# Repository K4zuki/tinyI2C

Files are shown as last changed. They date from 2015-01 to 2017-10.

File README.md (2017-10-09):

tinyI2C{-}
=======

This is a tiny UART-I2C converter software/hardware project using mbed conpatible microcontrollers.
The module converts UART command packets into I2C/SPI protocol or GPIO to read/write with
configurable pull-up/pull-down modes.

- the "FTDI" USB-UART cable to connect to host PC; from PC the module look only an USB-Serial port
    - up to 115200 boudrate UART to communicate
- up to 4 channel I2C ports with selectable speed
- one SPI port with 8/16 bits word, also selectable speed
- up to 2 x 8bit, General Purpose IO ports

```
TinyI2C/         <-- root
├── doc/      <-- document source
├── gui/      <-- PyQt4 based GUI source codes
├── mbed/     <-- mbed source codes
├── pcb/      <-- PCB design files for eagle
└── python/   <-- python module code with standalone test program
```

# Requirement
- Python 3
  `apt-get install python3`
- PySerial
  `pip3 install pyserial`
* mbed microcontrollers using LPC824(recommended)/LPC1768/LPC11U24/LPC11U35
  see [mbed.org](developer.mbed.org)

# Install
1. install python 3.3+ on your PC
2. install PySerial
3. (Windows only) if you use LpcXpresso 824 then install [mbed Serial port driver](http://developer.mbed.org/handbook/Windows-serial-configuration)

# Usage
1. write mbed program into your mbed
2. connect mbed to PC via Serial port
3. start gui software
4. select Serial port from dropdown list
5. you will be able to use up to 4 channels of I2C slaves and more!
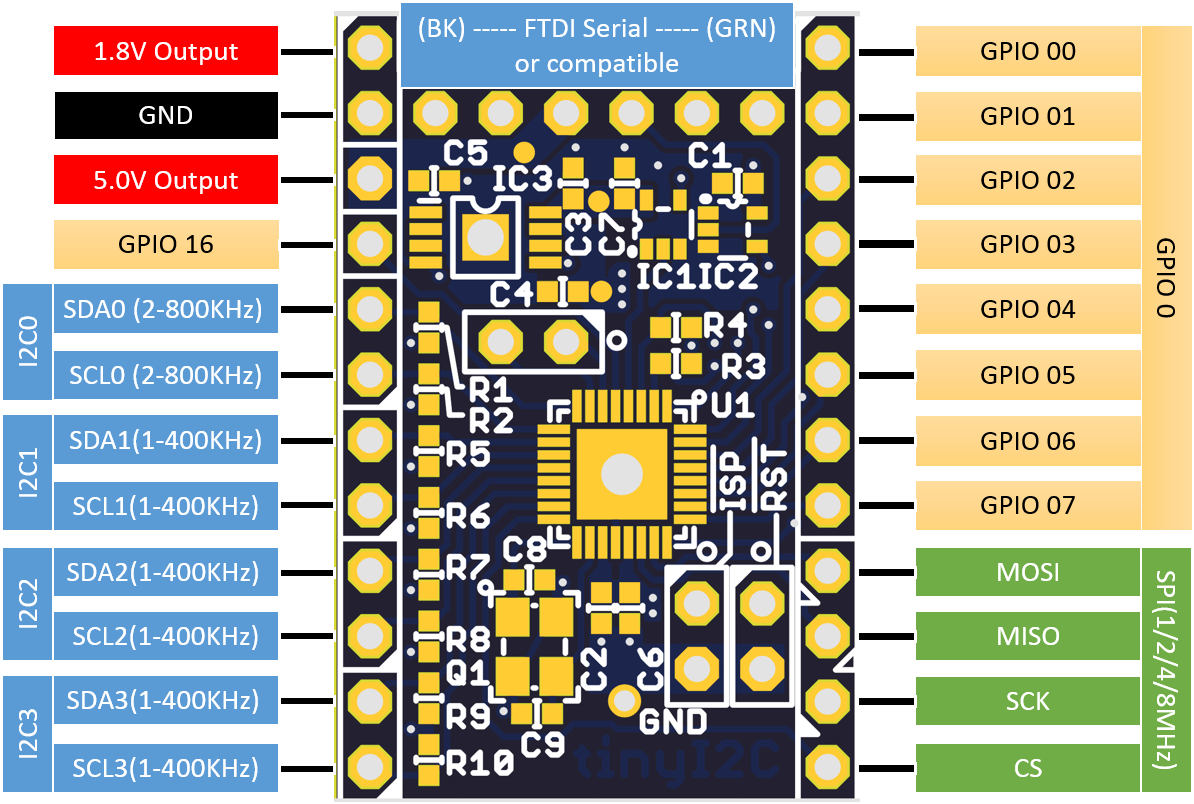
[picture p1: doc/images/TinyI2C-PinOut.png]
    * check PinOut for your usage! 

# Demo
  try `python/test.py`

## Demo GUI
GUI source codes placed in `gui/` which requires compilation
 (for now, _do it yourself_ basis).

GUI setup requires:

- PyQt5
- pyinstaller

```
$ pip3 install pyqt5 pyinstaller
```

### Compile GUI
On project root,
```
$ make gui
```

### Run GUI
On project root,
```
$ dist/TinyI2C
```

# Command set and protocol
- _this command character as well as packet structure is inspired(some copied) from
NXP Semiconductor's UART-I2C converter/controller, named **SC18IM700**._

- the command packet starts/ends with few number of characters: for starting(`head`)
character there are several choices but ending(`tail`) is always `'P'`, 0x50 in hex.
    - if only sending 'P', `tinyI2C` makes stop condition pulse (**without start condition**)
  on currently selected I2C bus and returns "ok" return packet.
- the `tinyI2C` watches its UART port \_Forever until_ it receives `tail`
  and counts received packet length by bytes (`plength`).
  then searches first character of the packet whether if matches one of registered `head` character.
    - if it does not match with any of valid `head` the device returns
  "command is not implemented" return packet.
- if valid head found it checks `plength-2` which is actual data packet length.
    - if you send an invalid packet, the device returns "bad packet" return packet.

## I2C
### `'S'` 0x53 I2C-bus START
### `'P'` 0x50 I2C-bus STOP, end of packet
- the protocol starts from `'S'`, which makes start condition on I2C bus, followed by 7bit I2C slave address and read(1)/write(0) command bit and,
  - to *Write* data into slave device: send data length to write(1~255) and actual data
  - to *Read* data from slave device: send data length to read(1~255)
- ends with sending `'P'` which makes stop condition on the bus
- return packet depends on command:
  - first, `"ACK"` or `"NAK"` depends on response from slave
  - *Read*: read data in hex sting (0xAA -> "AA") separated by ',' and ends by `ok`
  - *Write*: `ok`

- command packet: write 4 bytes to slave at 0x80(8bit)

| head  | slave address(W) | data length | binary data to write | tail  |
|:-----:|:---:|:---:|:---:|:-----:|
| S | 0x\_8 \_0 |  0x\_0 \_4  | 0x_D \_E \_A \_D \_B \_E \_A \_F | P |
| `'S'` | `'80'` | `'04'` | `'=>:=;>:?'` | `'P'` |
| 0x53  | 0x38 0x30 |  0x30 0x34  | 0x3D 0x3E 0x3A 0x3D 0x3B 0x3E 0x3A 0x3F | 0x50  |

- return packet

| result | head  | delimiter | tail |
|:---:|:-----:|:---:|:----:|
| sucess | "ACK" | , | "ok" |
|  fail  | "NAK" | , | "ok" |

- command packet: read 4 bytes from slave at 0x80(8bit)

| head | slave address(R\) | data length | tail |
|:----:|:---:|:---:|:----:|
|  S | 0x\_8 \_1 |  0x\_0 \_4  |  P |

- return packet

| result | head  | delimiter | data | tail |
|:---:|:-----:|:---:|:---:|:----:|
| sucess | "ACK" | , | actual data: "AA","BB","CC","DD", | "ok" |
|  fail  | "NAK" | , | dummy data: "C4","FE","E0","CA",  | "ok" |

- command packet: write and read 4 bytes to/from slave at 0x80(8bit)

| head | slave address(W) | data length | binary data to write | repeated start | slave address(R\) | data length | tail |
|:----:|:---:|:---:|:---:|:---:|:---:|:---:|:----:|
|  S | 0x\_8 \_0 |  0x\_0 \_4  | 0x_D \_E \_A \_D \_B \_E \_A \_F | S | 0x\_8 \_1 |  0x\_0 \_4  |  P |

- return packet

| result | head  | delimiter | data | tail |
|:---:|:-----:|:---:|:---:|:----:|
| sucess | "ACK" | , | actual data: "AA","BB","CC","DD", | "ok" |
|  fail  | "NAK" | , | dummy data: "C4","FE","E0","CA",  | "ok" |

### `'C'` 0x43 change channel
- you can select I2C channel by sending `'C'` and channel number `'0'`to`'3'` with `tail` char.

| head | channel | tail |
|:----:|:---:|:----:|
|  C | '0' |  P |
|  C | '1' |  P |
|  C | '2' |  P |
|  C | '3' |  P |

## SPI
### `'E'` 0x45 SPI transfer start

- minimum plength=8

| head | data length(W) | data length(R\) | binary data to write | tail |
|:----:|:---:|:---:|:---:|:----:|
|  E | 0x\_0 \_1 | 0x\_0 \_0 | 0x\_D \_E |  P |

- minimum plength=10(16bit)

| head | data length(W) | data length(R\) | binary data to write | tail |
|:----:|:---:|:---:|:---:|:----:|
|  E | 0x\_0 \_1 | 0x\_0 \_0 | 0x_D \_E \_A \_D |  P |

- write and read

| head | data length(W) | data length(R\) | binary data to write | tail |
|:----:|:---:|:---:|:---:|:----:|
|  E | 0x\_0 \_4 | 0x\_0 \_4 | 0x_D \_E \_A \_D \_B \_E \_A \_F |  P |

<!--
~~~
/*
"0|   1   2|   3   4|   5   6  7  8  9 10 11 12|13" //plength=14
"E| 0x\_0 \_1| 0x\_0 \_0| 0x_D \_E| P"                   //minimum plength=8
"E| 0x\_0 \_1| 0x\_0 \_0| 0x_D \_E|_A \_D| P"             //minimum plength=10(16bit)
"E| 0x\_0 \_4| 0x\_0 \_0| 0x_D \_E \_A \_D \_B \_E \_A \_F| P" //write
"E| 0x\_0 \_4| 0x\_0 \_4| 0x_D \_E \_A \_D \_B \_E \_A \_F| P" //write and read
*/
~~~
-->

## GPIO
This is a subset of [R/W commands](#internal-registers); only access GPIO's status registers.

### `'I'` 0x49 read GPIO port register
### `'O'` 0x4F write to GPIO port register

| head | GPIO | tail |
|:----:|:----:|:----:|
|  I | '0'  |  P |
|  I | '1'  |  P |

| head | GPIO | data | tail |
|:----:|:----:|:---:|:----:|
|  O | '0'  | 0x\_A \_A |  P |
|  O | '1'  | 0x\_A \_A |  P |

| register | name in python | purpose |
|:---:|:---:|:---|
| 0 | GPIO0_STAT | status of GPIO 0 |
| 1 | GPIO1_STAT | status of GPIO 1 |

## Internal registers
### `'R'` 0x52 read internal register
### `'W'` 0x57 write to internal register
- single register read

| head | register | tail |
|:----:|:---:|:----:|
|  R | '0' |  P |
|  R | '1' |  P |

- multi registers read

| head | register(1) | register(2) | ... | register(n) | tail |
|:----:|:---:|:---:|:---:|:---:|:----:|
|  R | '0' | '1' | ... | '5' |  P |
|  R | '1' | '0' | ... | '9' |  P |

- return packet's order is same as command packet's order

: multi registers write

| head | register(1) | register data (1) | register(2) | register data (2) | ... | register(n) | register data (n) | tail |
|:----:|:---:|:---:|:---:|:---:|:---:|:---:|:---:|:----:|
|  W | '0' | 0x\_A \_A | '1' | 0x\_A \_B | ... | '5' | 0x\_A \_D |  P |
|  W | '1' | 0x\_A \_A | '0' | 0x\_A \_B | ... | '9' | 0x\_A \_D |  P |

- return packet's order is same as command packet's order

| register | name in python | purpose |
|:---:|:---:|:---|
| 0 | CHIP_ID | converter's chip ID |
| 1 | GPIO0_STAT | status of GPIO 0 |
| 2 | GPIO1_STAT | status of GPIO 1 |
| 4 | GPIO1_CONF | GPIO 0 IO configuration |
| 3 | GPIO0_CONF | GPIO 1 IO configuration |
| 5 | I2C_CONF | I2C channel 1~4 speed configuration  |
| 6 | SPI_CONF | SPI speed and polarity configuration |

| register 0  | command | CHIP_ID |
|:---:|:---:|:---|
| [7\.\.\.0\] | R/W | returns chip ID character: |
| | | '0'- LPC824 |
| | | '1'- LPC1768 |
| | | '2'- LPC11U24 or LPC11U35  |

| register 1  | command | GPIO0_STAT |
|:---:|:---:|:---|
| [7\.\.\.0\] | R | behavior changes depend on corresponding bit of GPIO0_CONF register |
| | | 1: reads output setting |
| | | 0: reads input of the pin |
| | W | behavior changes depend on corresponding bit of GPIO0_CONF register |
| | | 1: writes data to the pin |
| | | 0: do nothing |

| register 2  | command | GPIO1_STAT |
|:---:|:---:|:---|
| | | **if GPIO1 is not enabled, access to this register will be ignored** |
| [7\.\.\.0\] | R | behavior changes depend on corresponding bit of GPIO1_CONF register  |
| | | 1: reads output setting |
| | | 0: reads input of the pin |
| | W | behavior changes depend on corresponding bit of GPIO1_CONF register  |
| | | 1: writes data to the pin |
| | | 0: do nothing |

| register 3  | command | GPIO0_CONF |
|:---:|:---:|:---|
| [7\.\.\.0\] | R | Reads each pin's Input/Output conditions: |
| | | 1 = the pin is set to output |
| | | 0 = the pin is set to input with internal pullup |
| | W | Sets each pin's Input/Output configurations: |
| | | 1: sets the pin to an Output. output level is set by corresponding bit of GPIO0_STAT register |
| | | 0: sets the pin to an Input with internal pull-up connected |

| register 4  | command | GPIO1_CONF |
|:---:|:---:|:---|
| | | **if GPIO1 is not enabled, access to this register will be ignored** |
| [7\.\.\.0\] | R | Reads each pin's Input/Output conditions: |
| | | 1: the pin is set to output |
| | | 0: the pin is set to input with internal pullup |
| | W | Sets each pin's Input/Output configurations: |
| | | 1: sets the pin to an Output. output level is set by corresponding bit of GPIO1_STAT register |
| | | 0: sets the pin to an Input with internal pull-up connected |

| register 5  | command | I2C_CONF |
|:---:|:---:|:---|
| [7\.\.\.6\] | R/W | Read/Write clock configuration of I2C1 |
| | | 11: I2C1 is set to operate in 800kHz clock |
| | | 10: I2C1 is set to operate in 600kHz clock |
| | | 01: I2C1 is set to operate in 400kHz clock |
| | | 00: I2C1 is set to operate in 200kHz clock |
| [5\.\.\.4\] | | Read/Write clock configuration of I2C2; **if I2C2 is not enabled, access to this bitfield will be ignored** |
| | | 11: I2C2 is set to operate in 400kHz clock |
| | | 10: I2C2 is set to operate in 300kHz clock |
| | | 01: I2C2 is set to operate in 200kHz clock |
| | | 00: I2C2 is set to operate in 100kHz clock |
| [3\.\.\.2\] | | Read/Write clock configuration of I2C3; **if I2C3 is not enabled, access to this bitfield will be ignored** |
| | | 11: I2C3 is set to operate in 400kHz clock |
| | | 10: I2C3 is set to operate in 300kHz clock |
| | | 01: I2C3 is set to operate in 200kHz clock |
| | | 00: I2C3 is set to operate in 100kHz clock |
| [1\.\.\.0\] | | Read/Write clock configuration of I2C4; **if I2C4 is not enabled, access to this bitfield will be ignored** |
| | | 11: I2C4 is set to operate in 400kHz clock |
| | | 10: I2C4 is set to operate in 300kHz clock |
| | | 01: I2C4 is set to operate in 200kHz clock |
| | | 00: I2C4 is set to operate in 100kHz clock |

| register 6  | command | SPI_CONF |
|:---:|:---:|:---|
| [7\] | R/W | Not used |
| [6\.\.\.4\] | | Read/Write clock configuration of SPI |
| | | 111: SPI is set to operate in 8MHz clock  |
| | | 110: SPI is set to operate in 7MHz clock  |
| | | ... |
| | | 001: SPI is set to operate in 2MHz clock  |
| | | 000: SPI is set to operate in 1MHz clock  |
| [3\] | | Reads/Wreite polarity of CE print |
| | | 1: CE is set to HIGH-active |
| | | 0: CE is set to LOW-active |
| [2\] | | Read/Write word size setting of SPI |
| | | 1: 16 bit word |
| | | 0: 8 bit word |
| [1\.\.\.0\] | | Read/Write SPI mode |
| | | 11: SPI is set to operate in clock mode 3 |
| | | 10: SPI is set to operate in clock mode 2 |
| | | 01: SPI is set to operate in clock mode 1 |
| | | 00: SPI is set to operate in clock mode 0 |

# Contribution by
Kazuki Yamamoto ( <k.yamamoto.08136891@gmail.com> )

# License
- [CC-BY-SA](http://creativecommons.org/licenses/by-sa/4.0/legalcode)
- [CC-BY-SA 日本語](http://creativecommons.org/licenses/by-sa/2.1/jp/legalcode)

# Author

[K4zuki](https://github.com/K4zuki)

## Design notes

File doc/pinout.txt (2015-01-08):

pin IO      func
1   P0_13   UART_RTS
2   P0_12   !ISP        _GPIO17
3   P0_5    !RESET
4   P0_4    UART_TX
5   P0_28   _GPIO16
6   P0_3    SWCLK
7   P0_2    SWDIO
8   P0_11   I2C0_SDA
9   P0_10   I2C0_SCL
10  P0_16   I2C1_SDA    _GPIO15
11  P0_27   I2C1_SCL    _GPIO14
12  P0_26   I2C2_SDA    _GPIO13
13  P0_25   I2C2_SCL    _GPIO12
14  P0_24   I2C3_SDA    _GPIO11
15  P0_15   I2C3_SCL    _GPIO10
16  P0_1    UART_CTS
17  P0_9    CS
18  P0_8    SCLK
19  VDD     VDD
20  VREFN   GND
21  VREFP   VDD
22  P0_7    MISO
23  P0_6    MOSI
24  P0_0    UART_RX
25  P0_14   _GPIO07
26  P0_23   _GPIO06
27  P0_22   _GPIO05
28  P0_21   _GPIO04
29  P0_20   _GPIO03
30  P0_19   _GPIO02
31  P0_18   _GPIO01
32  P0_17   _GPIO00
33  VSS     GND

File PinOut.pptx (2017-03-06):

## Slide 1

1.8V Output

(BK) ----- FTDI Serial ----- (GRN)
or compatible

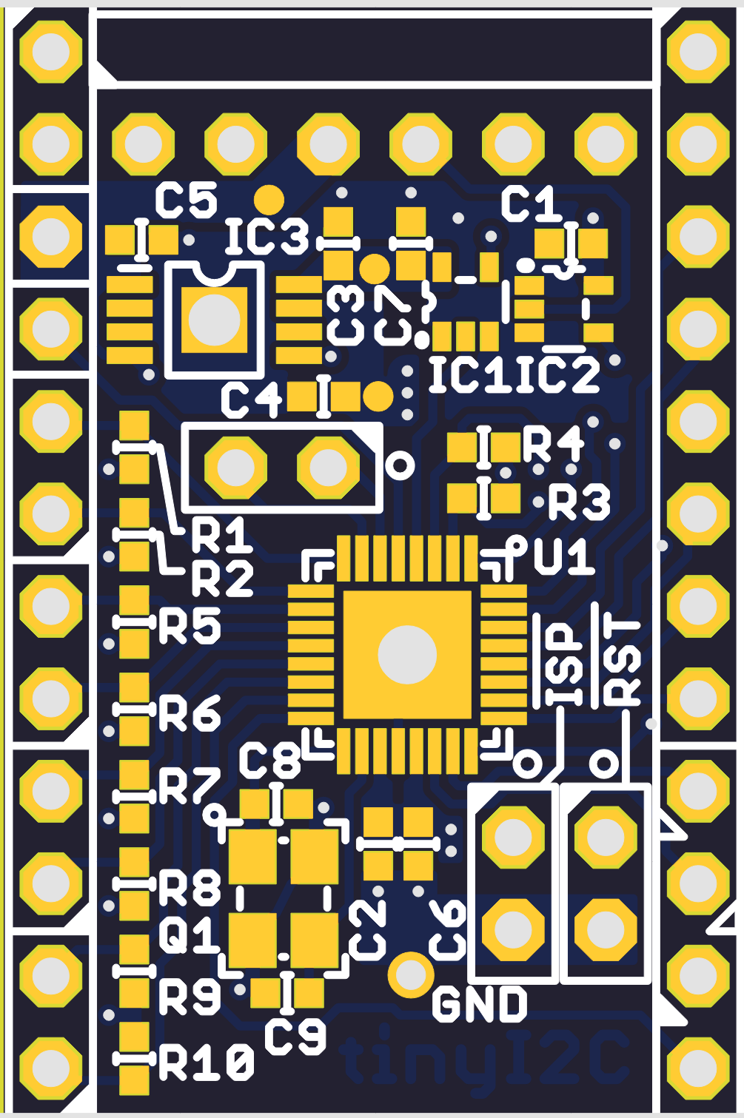
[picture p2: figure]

GPIO 00

GND

GPIO 01

5.0V Output

GPIO 16

GPIO 02

GPIO 03

SDA0 (2-800KHz)

GPIO 0

GPIO 04

I2C0

SCL0 (2-800KHz)

GPIO 05

I2C1

SDA1(1-400KHz)

SCL1(1-400KHz)

GPIO 06

GPIO 07

I2C2

SDA2(1-400KHz)

MOSI

SDA3(1-400KHz)

SCL2(1-400KHz)

MISO

SCK

SPI(1/2/4/8MHz)

I2C3

SCL3(1-400KHz)

CS

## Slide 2

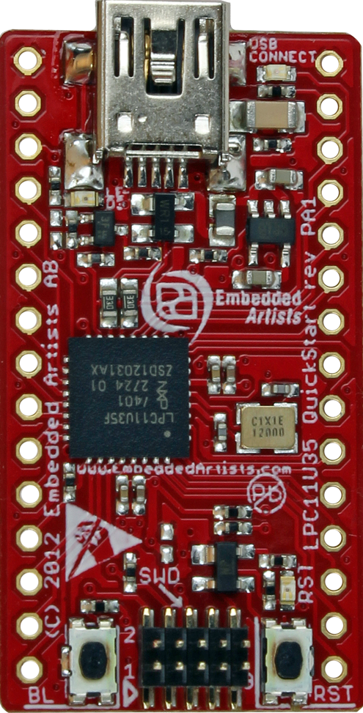
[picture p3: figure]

GND

VBUS 5.0V

GND

3.3V Output

CS

SPI(1/2/4/8MHz)

MISO

MOSI

SDA0 (2-800KHz)

SCK

SCL0 (2-800KHz)

I2C0

GPIO 00

GPIO 01

GPIO 16

GPIO 02

GPIO 15

GPIO 0

GPIO 03

GPIO 04

GPIO 14

GPIO 05

GPIO 06

GPIO 13

GPIO 07

GPIO 12

GPIO 11

GPIO 17

GPIO 10

GPIO 1

GPIO 1

GPIO 1

Image from http://www.embeddedartists.com/sites/default/files/styles/ea_photos_list/public/image/product/qsb_lpc11u35.png

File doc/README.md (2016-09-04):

+----------------+-----------+------------+------------+----------+----------+----------+------------+-------------------+-------------------+
|     Macro      |   Board   |  Function\ |            |          |          |          |            |                   |                   |
+================+===========+============+============+==========+==========+==========+============+===================+===================+
|                |           | **always**\| **always**\|          |          |          | **always**\|    **always**\    |                   |
|                |           |  **UART**  |  **I2C0**  | **I2C1** | **I2C2** | **I2C3** |  **SPI**   | **GPIO0[7\.\.0]** | **GPIO1[7\.\.0]** |
+----------------+-----------+------------+------------+----------+----------+----------+------------+-------------------+-------------------+
| **#QUAD_I2C**  | LPC824MAX |   USBTX    |  I2C_SDA   |   P0_6   |  P0_23   |  P0_21   |   P0_26    |   P0_27           |                   |
+----------------+-----------+------------+------------+----------+----------+----------+------------+-------------------+-------------------+
|                |           |   USBRX    |  I2C_SCL   |  P0_14   |  P0_22   |  P0_20   |   P0_25    |   P0_13           |                   |
+----------------+-----------+------------+------------+----------+----------+----------+------------+-------------------+-------------------+
|                |           |            |            |          |          |          |   P0_24    |   P0_17           |                   |
+----------------+-----------+------------+------------+----------+----------+----------+------------+-------------------+-------------------+
|                |           |            |            |          |          |          |   P0_15    |   P0_16           |                   |
+----------------+-----------+------------+------------+----------+----------+----------+------------+-------------------+-------------------+
|                |           |            |            |          |          |          |            |   P0_28           |                   |
+----------------+-----------+------------+------------+----------+----------+----------+------------+-------------------+-------------------+
|                |           |            |            |          |          |          |            |   P0_18           |                   |
+----------------+-----------+------------+------------+----------+----------+----------+------------+-------------------+-------------------+
|                |           |            |            |          |          |          |            |   P0_12           |                   |
+----------------+-----------+------------+------------+----------+----------+----------+------------+-------------------+-------------------+
|                |           |            |            |          |          |          |            |   P0_19           |                   |
+----------------+-----------+------------+------------+----------+----------+----------+------------+-------------------+-------------------+
| **#QUAD_I2C**\ |  TINYI2C  |    P0_4    |  I2C_SDA   |  P0_16   |  P0_26   |  P0_24   |    P0_6    |   P0_14           |                   |
| **+ #TINYI2C** |           |            |            |          |          |          |            |                   |                   |
+----------------+-----------+------------+------------+----------+----------+----------+------------+-------------------+-------------------+
| **+ #TINYI2C** |  SSCI824  |    P0_0    |  I2C_SCL   |  P0_27   |  P0_25   |  P0_15   |    P0_7    |   P0_23           |                   |
+----------------+-----------+------------+------------+----------+----------+----------+------------+-------------------+-------------------+
|                |           |            |            |          |          |          |   P0_13    |   P0_22           |                   |
+----------------+-----------+------------+------------+----------+----------+----------+------------+-------------------+-------------------+
|                |           |            |            |          |          |          |    P0_1    |   P0_21           |                   |
+----------------+-----------+------------+------------+----------+----------+----------+------------+-------------------+-------------------+
|                |           |            |            |          |          |          |            |   P0_20           |                   |
+----------------+-----------+------------+------------+----------+----------+----------+------------+-------------------+-------------------+
|                |           |            |            |          |          |          |            |   P0_19           |                   |
+----------------+-----------+------------+------------+----------+----------+----------+------------+-------------------+-------------------+
|                |           |            |            |          |          |          |            |   P0_18           |                   |
+----------------+-----------+------------+------------+----------+----------+----------+------------+-------------------+-------------------+
|                |           |            |            |          |          |          |            |   P0_17           |                   |
+----------------+-----------+------------+------------+----------+----------+----------+------------+-------------------+-------------------+
|  **#TINYI2C**  |  TINYI2C  |    P0_4    |  I2C_SDA   |          |          |          |    P0_6    |   P0_14           |   P0_12           |
+----------------+-----------+------------+------------+----------+----------+----------+------------+-------------------+-------------------+
|                |  SSCI824  |    P0_0    |  I2C_SCL   |          |          |          |    P0_7    |   P0_23           |   P0_28           |
+----------------+-----------+------------+------------+----------+----------+----------+------------+-------------------+-------------------+
|                |           |            |            |          |          |          |   P0_13    |   P0_22           |   P0_16           |
+----------------+-----------+------------+------------+----------+----------+----------+------------+-------------------+-------------------+
|                |           |            |            |          |          |          |    P0_1    |   P0_21           |   P0_27           |
+----------------+-----------+------------+------------+----------+----------+----------+------------+-------------------+-------------------+
|                |           |            |            |          |          |          |            |   P0_20           |   P0_26           |
+----------------+-----------+------------+------------+----------+----------+----------+------------+-------------------+-------------------+
|                |           |            |            |          |          |          |            |   P0_19           |   P0_25           |
+----------------+-----------+------------+------------+----------+----------+----------+------------+-------------------+-------------------+
|                |           |            |            |          |          |          |            |   P0_18           |   P0_24           |
+----------------+-----------+------------+------------+----------+----------+----------+------------+-------------------+-------------------+
|                |           |            |            |          |          |          |            |   P0_17           |   P0_15           |
+----------------+-----------+------------+------------+----------+----------+----------+------------+-------------------+-------------------+

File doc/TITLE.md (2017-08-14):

---
title: NXPのICでNXPのICをエミュレートさせてみた本
abstract: NXP社のLPCマイクロコントローラ3種でNXPのI^2^CインタフェースIC
    "SC18IM700" をエミュレートさせてみた
circle: KY技研
author: "@_K4ZUKI_"
date: 技術書典２/2017-Apr
comiket: "技術書典２"
year: "2017"
publisher: "秋葉原キンコーズで印刷製本予定"
docrevision: "1.0"
# short-hash: (git short hash)

documentclass: book
printer: true
# papersize: b5paper
# mainfont: RictyDiminished-Regular
# sansfont: RictyDiminished-Regular
# monofont: RictyDiminished-Regular
# mainlang: Japanese
# CJKoptions: BoldFont=RictyDiminished-Bold,
#   ItalicFont=RictyDiminished-Oblique,
#   BoldItalicFont=RictyDiminished-BoldOblique
# CJKmainfont: RictyDiminished-Regular
# CJKsansfont: RictyDiminished-Regular
# CJKmonofont: RictyDiminished-Regular
# geometry: top=30truemm,bottom=30truemm,left=20truemm,right=20truemm
keywords: keyword
secPrefix: Chapter
linkcolor: black
urlcolor: black
citecolor: black
chapter: true
listings: true
codeBlockCaptions: true
listingTitle: 'List'
listingTemplate: '---**$$listingTitle$$ $$i$$$$titleDelim$$ $$t$$**---'
front: images/TinyI2C-PinOut.png
---

\\newpage
# まえがき {.unnumbered}
このドキュメントは、NXP社のLPCマイクロコントローラ3種でNXPのI^2^CインタフェースIC
**`SC18IM700`** をエミュレートしつつ拡張もするプログラム群
___TinyI2Cプロジェクト___ を解説する本です。

筆者が仕事で同じスレーブアドレスのI^2^Cデバイスを複数同時に（といっても4個程度）
PCから操作する必要があったことから、USBなどとI^2^Cバスの相互通信が可能なICを
探していました。その時に見つけたのが **`SC18IM700`** でした。いろいろあって
サンプルを入手もした[^mbed_fest] のですが、必要なバスが1ポート分しかないので
別の方法を考えることにしました。

**`SC18IM700`** のコマンド体系が使いやすかったので一部をそのまま用いつつ、
例によってmbed^TM^対応マイコンを使おうと考え、 **`LPC824`** シリーズマイコンが
I^2^Cマスタ機能を _4基_ 搭載しているということから条件が一致しました。

この本は プロジェクトの概要説明とコマンドセット/Pythonライブラリ
の解説をします。いまのところ特にオチは用意してません~~がまたも６０ページ前後の
超大作になりそうです~~ 。
<!-- mbed^TM^ LPC1768 / LPC824 / LPC11U35に移植した話、TinyI2C基板の回路図、
それぞれのピン配置図ギャラリー、GUI -->

<#include "1.0_tinyI2Cabstract.md">
<#include "2.0_Commands.md">
<#include "3.0_PythonAPI.md">
<#include "9.1_RevHistory.md">

<!--  -->
[^mbed_fest]: 2014年のmbed祭りのいずれかで懇親会のおみやげにサンプルブックを入手したとかだったような

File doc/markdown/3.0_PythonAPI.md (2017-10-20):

# Python ライブラリ
この章では`TinyI2C`をPCなどから利用するためのPython実装を紹介します。
このライブラリには以下のPythonモジュール（ライブラリ）が必要です：

- PySerial

## コンストラクタ

+-------------------------------------------------------------------------------+
| **`TinyI2c(  str port = 'com1', str baud = '115200' )`**                      |
+===============================================================================+
| - **argument**                                                                |
|     - **`port`** Serial/UART port name; "COM1", "/dev/ttyUSB0" etc.           |
|     - **`baud`** UART baudrate: 115200 or need to align with firmware         |
|      setting for other rate                                                   |
+-------------------------------------------------------------------------------+
| `port`につながっている`TinyI2C`デバイスに接続する\                            |
| ＊ボーレートを変更する場合はファームウェアにも変更が必要                      |
+-------------------------------------------------------------------------------+

\\newpage
## UART操作API
+-------------------------------------------------------------------------------+
| **`TinyI2c.raw_write( str data = "C4FEE0CA"  )`**                             |
+===============================================================================+
| - **argument**                                                                |
|     - **`data`** raw data to send, as text string                             |
| - **return**                                                                  |
|     - None                                                                    |
+-------------------------------------------------------------------------------+
| 生データをUART（COMポート）に出力する                                         |
+-------------------------------------------------------------------------------+

<!--  -->

+-------------------------------------------------------------------------------+
| **`TinyI2c.raw_read(  )`**                                                    |
+===============================================================================+
| - **return**                                                                  |
|     - _ser.readline().strip()                                                 |
+-------------------------------------------------------------------------------+
|  UARTポートから生データを受け取る                                             |
+-------------------------------------------------------------------------------+

\\newpage
## I^2^Cバス操作API

+-------------------------------------------------------------------------------+
| **`TinyI2c.start(   )`**                                                      |
+===============================================================================+
| - **return**                                                                  |
|     - None                                                                    |
+-------------------------------------------------------------------------------+
|  現在のI^2^Cポートにスタートコンディションを発行する                          |
+-------------------------------------------------------------------------------+

<!--  -->

+-------------------------------------------------------------------------------+
| **`TinyI2c.stop(   )`**                                                       |
+===============================================================================+
| - **return**                                                                  |
|     - None                                                                    |
+-------------------------------------------------------------------------------+
|  現在のI^2^Cポートにストップコンディションを発行する                          |
+-------------------------------------------------------------------------------+

<!--  -->

+-------------------------------------------------------------------------------+
| **`TinyI2c.read( int address, int length = 1 )`**                             |
+===============================================================================+
| - **argument**                                                                |
|     - **`address`** *8bit* I^2^C slave address                                |
|     - **`length `** data length to read from slave                            |
| - **return**                                                                  |
|     - str raw_read()                                                          |
+-------------------------------------------------------------------------------+
| 現在のI^2^Cポートにつながっているスレーブデバイスから`length`バイト読み出す   |
+-------------------------------------------------------------------------------+

<!--  -->

+-------------------------------------------------------------------------------+
| **`TinyI2c.write( int address, int data = 0 )`**                              |
+===============================================================================+
| - **argument**                                                                |
|     - **`address`** *8bit* I^2^C slave address                                |
|     - **` data  `** data to write                                             |
| - **return**                                                                  |
|     - str raw_read()                                                          |
+-------------------------------------------------------------------------------+
| 現在のI^2^Cポートにつながっているスレーブデバイスに`data`を書き込む           |
+-------------------------------------------------------------------------------+

<!--  -->

+-------------------------------------------------------------------------------+
| **`TinyI2c.write_and_read( int address, int wdata = 0, int rlength = 1 )`**|
+===============================================================================+
| - **argument**                                                                |
|     - **`address`** *8bit* I^2^C slave address                                |
|     - **` wdata `** data to write                                             |
|     - **`rlength`** data length to read from slave                            |
| - **return**                                                                  |
|     - str raw_read()                                                          |
+-------------------------------------------------------------------------------+
| 現在のI^2^Cポートにつながっているスレーブデバイスに`data`を書き込んだあとで   |
| `length`バイト読み出す                                                        |
+-------------------------------------------------------------------------------+

<!--  -->

+-------------------------------------------------------------------------------+
| **`TinyI2c.setChannel( int channel = 0 )`**                                   |
+===============================================================================+
| - **argument**                                                                |
|     - **`channel`** I^2^C bus channel 1~4                                     |
| - **return**                                                                  |
|     - str raw_read()                                                          |
+-------------------------------------------------------------------------------+
| I^2^Cポートを変更する。Cコマンドのラッパー関数                                |
+-------------------------------------------------------------------------------+

\\newpage
## SPIバス操作コマンドAPI

+------------------------------------------------------------------------------------------------+
| **`TinyI2c.write_and_read_SPI( int wlength = 1, int rlength = 0, int data = 0xC4FEE0CA )`**    |
+================================================================================================+
| - **argument**                                                                                 |
|     - **`wlength`** _word length_ to write                                                     |
|     - **`rlength`** _word length_ to send dummy data                                           |
|     - **` data  `** valid data to write                                                        |
| - **return**                                                                                   |
|     - str raw_read()                                                                           |
+------------------------------------------------------------------------------------------------+
| SPIバスに8または16ビットデータ列を`wlength` _ワード_ 書き込んだあと                            |
| ダミーデータを`rlength` _ワード_ 書込む                                                        |
+------------------------------------------------------------------------------------------------+

\\newpage
## 内部レジスタ操作コマンド

+-------------------------------------------------------------------------------+
| **`TinyI2c.reg_read( str registers = "012" )`**                               |
+===============================================================================+
| - **argument**                                                                |
|     - **`registers`**                                                         |
| - **return**                                                                  |
|     - str raw_read()                                                          |
+-------------------------------------------------------------------------------+
| `registers`のデータをまとめて読み出す                                         |
+-------------------------------------------------------------------------------+

<!--  -->

+-------------------------------------------------------------------------------+
| **`TinyI2c.reg_write( list pair = [ ('1', 0xFF),] )`**                        |
+===============================================================================+
| - **argument**                                                                |
|     - **`pair`** list of touple                                               |
|         - **`register`** register number                                      |
|         - **`  data  `** data to write to register                            |
| - **return**                                                                  |
|     - str raw_read()                                                          |
+-------------------------------------------------------------------------------+
| それぞれの`register`に、対応する`data`を書き込む\                             |
| `register`は'0'~'6'もしくは以下の定義済み変数が使える：                       |
|                                                                               |
| - '0'     =>   `CHIP_ID`                                                      |
| - '1'     =>   `GPIO0_STAT`                                                   |
| - '2'     =>   `GPIO1_STAT`                                                   |
| - '4'     =>   `GPIO1_CONF`                                                   |
| - '3'     =>   `GPIO0_CONF`                                                   |
| - '5'     =>   `I2C_CONF`                                                     |
| - '6'     =>   `SPI_CONF`                                                     |
+-------------------------------------------------------------------------------+

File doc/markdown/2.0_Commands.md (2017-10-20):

# コマンドセットとプロトコル仕様

+-------------------------------------------------------------------------------+
| これらのコマンド文字とパケットの構造はNXP社のインタフェースIC **`SC18IM700`** |
| の仕様<sub>~~をパクっt~~</sub>に**_強く_**インスパイアされています。          |
+-------------------------------------------------------------------------------+

## 基本的なプロトコル仕様

- コマンドパケットの開始/終了には予約されている文字を1文字ずつ使います。パケットの
先頭文字(**`head`**)には何種類かありますが終端(**`tail`**)は常にアスキーの **`P`** または16進の
**`0x50`** を用います。
    - 先頭文字なしで **`P`** を送ると、現在選択されている I^2^Cバスで
    （スタートコンディション動作を起こさずに）ストップコンディション動作を行い、
    **"ok"** パケットが返却されます。
- **`head/tail`** 以外のデータはすべて1バイトを2バイトに分割して送信します。
  分割されたそれぞれの4ビットはLSBに割当てます。
  各MSBは0x03~0x0Fの任意の4ビットをマスクとして加えます。
    - 例：マスクを0x30として0x**A5** → 0x3**A** 0x3**5**
    - _0x30をマスクにするとアスキー文字列として送ることができます。_
```table
---
caption: アスキー文字一覧（抜粋）
table-width: 0.6
alignment: CCCDCCC
header: True
# inline markdown
Markdown: True
include: data/asciitable.csv
---
```

- **`tinyI2C`** モジュールはパケットを受けとるUARTポートに終端文字が送られてくるのを
(永久に)監視し続け、送られると最初にパケット文字列の長さ(`plength`)を測ります。
次に先頭文字がいずれかのコマンド文字と一致するか確認します。
    - 先頭文字が無効な場合は **"command is not implemented"** パケットが返却されます。
    - 先頭文字が有効な場合は有効文字列長(`plength - 2`：パケット長から先頭と終端
      の2文字を引いた長さ)を確認します。
        - 残念ながら文字列がそのコマンドの最低文字列長に満たない場合は **"bad packet"**
          パケットが返却されます。
    - 有効なコマンドパケットと確認できると **`TinyI2C`** モジュールはコマンドを実行し、結果を
      返却パケットとしてホストに返します。返却パケットはデータを伴う場合は各データバイトを
      16進文字列に変換し、コンマ区切りにされます。エラーでない返却パケットの終端は常に
      "ok"という文字列です。

## I^2^Cバス操作コマンド
### `'S'` 0x53 I^2^C-bus START
### `'P'` 0x50 I^2^C-bus STOP, end of packet

1. プロトコルはアスキーの **`S`** で開始され、同時に I^2^Cバスにスタートコンディションを発行します。
  その直後に7ビットの I^2^Cスレーブアドレスと`R(1)`または`W(0)`のコマンドビットが続きます。\
  このあと、
    - コマンドビットが`W(0)`（書込み）：送られるデータの長さ（1~255）と実際のデータを送る
    - コマンドビットが`R(1)`（読出し）：読みだすデータの長さ（1~255）を送る
1. パケットは **`P`** で終端します。このとき I^2^Cバスにストップコンディションを発行します。
1. 返却パケットはコマンドビットの内容に依存します。
    - 常に最初はスレーブの応答によって`ACK`または`NAK`が返ります。\
      その後、
        - コマンドビットが`W(0)`（書込み）：**`ok`** が返ります
        - コマンドビットが`R(1)`（読出し）：8ビットごとに16進数の文字列と
          終端の **`ok`** がコンマ区切りで返ります

#### 書込みのみを行う例

_8bit_ スレーブアドレス0x80に4バイト書込む コマンドパケット例

該当するI^2^Cバスの動き

返却パケット

#### 読出しのみを行う例

_8bit_ スレーブアドレス0x80から4バイト読出すコマンドパケット例

返却パケット

#### 書き込んだ後読み出す例

スレーブアドレス0x80に4バイトずつ書込み・読出しを行う コマンドパケット例

返却パケット

### `'C'` 0x43 change channel
**`C`** に続いてチャネル番号と終端を送ると I^2^Cバスを変更できます。チャネル番号は
アスキー文字の'0'~'3'です。

- _サポートされていないチャネルを選択すると強制的に**チャネル0**が選択されます。_

<!-- `Out/commandC.tmd`{.include} -->
```table
---
# caption:
alignment: CCC
table-width: 0.8
# inline markdown
markdown: True
header: True
caption: I2Cバス変更パケットの例
include: data/commandC.csv
---
```

## SPIバス操作コマンド
### `'E'` 0x45 SPI transfer start
SPIバスの操作をします。8または16ビットワードが選択できます
（詳細は[R/Wコマンド](#internal-registers)参照）。

- データ長はワード数のことです。8ビットと16ビットで最短有効パケット長が
  異なるので注意が必要です。データ長の違いは書込み/読出しともに適用されます。
  16ビットワード時に奇数バイトのデータを送ると _`bad packet`_ エラーパケットが
  返却されます。
- SPIフラッシュなど、読出しコマンドを書き込んで一気に大量に読むときは16ビット
  のほうが早く読み出せますが、コマンドが奇数バイトの場合は8ビットワードに
  する必要があります。

8ビットワードで1ワード書き込む例(minimum plength = 8)

16ビットワードで1ワード書き込む例(minimum plength = 10)

8ビットワードで2ワードずつ読み書きする例

\\newpage
## GPIO操作コマンド

```table
---
header: False
alignment: C
markdown: True
table-width: 0.8
---
これらは内部レジスタ操作コマンド（[R/Wコマンド](#internal-registers)）の
サブセットになっています。
```

**`I`** または **`O`** でプロトコルを開始します。指定できるGPIOポート番号は
`0`または`1`のみです。ハードウェアによってはポート1が存在しない場合があります。
_サポートされていないIOポートを選択すると強制的に`0xAA`を返却します。_

**`I`** コマンドでGPIOポートの状態を読むとき、または **`W`** でGPIOの状態を
変えるとき、該当するGPIOポートの設定レジスタの内容によって動作が変わります。

### `'I'` 0x49 read GPIO port register
### `'O'` 0x4F write to GPIO port register

```table
---
alignment: CCCC
table-width: 0.5
---
head,GPIO,data,tail
I,'0',,P
O,'0',0x?A ?A,P
I,'1',,P
O,'1',0x?A ?A,P
```

<!--  -->
| register | name in python | purpose |
|:---:|:---:|:---|
| 0 | GPIO0_STAT | status of GPIO 0 |
| 1 | GPIO1_STAT | status of GPIO 1 |

\\newpage
## 内部レジスタ操作コマンド {#internal-registers}
### `'R'` 0x52 read internal register
### `'W'` 0x57 write to internal register

TinyI2Cモジュール内部の設定レジスタの操作をします。
返却パッケットのデータはコマンドパケットのレジスタ指定順で返却されます。

Table: 単一レジスタから読出す例

| head | register | tail |
|:----:|:---:|:----:|
|  R | '0' |  P |
|  R | '1' |  P |

Table: 複数のレジスタから一度に読み出す例

| head | register(1) | register(2) | ... | register(n) | tail |
|:----:|:---:|:---:|:---:|:---:|:----:|
|  R | '0' | '1' | ... | '5' |  P |
|  R | '1' | '0' | ... | '9' |  P |

```table
---
# table-width:
header: True
# inline markdown
markdown: True
alignment: CCCCCCCCC
caption: multi registers write
include: data/commandRandW_multi.csv
---
```

\\newpage
#### レジスタのリスト {-}
```table
---
# table-width:
header: True
# inline markdown
markdown: True
alignment: CCC
include: data/register_list.csv
---
```

\\newpage
#### レジスタ０(CHIP_ID) {-}



```table
---
width:
  - 0.2
  - 0.5
header: True
# inline markdown
markdown: True
include: data/register0.csv
---
```

\\newpage
#### レジスタ１(GPIO0_STAT) {-}



```table
---
width:
  - 0.2
  - 0.5
header: True
# inline markdown
markdown: True
include: data/register1.csv
---
```

\\newpage
#### レジスタ３(GPIO0_CONF) {-}


<!--  -->
```table
---
width:
  - 0.2
  - 0.5
header: True
# inline markdown
markdown: True
include: data/register3.csv
---
```

\\newpage
#### レジスタ２(GPIO1_STAT) {-}



```table
---
width:
  - 0.2
  - 0.5
header: True
# inline markdown
markdown: True
include: data/register2.csv
---
```

\\newpage
#### レジスタ４(GPIO1_CONF) {-}


```table
---
width:
  - 0.2
  - 0.5
header: True
# inline markdown
markdown: True
include: data/register4.csv
---
```

\\newpage
#### レジスタ５(I2C_CONF) {-}


```table
---
width:
  - 0.2
  - 0.5
header: True
# inline markdown
markdown: True
include: data/register5.csv
---
```

\\newpage
#### レジスタ６(SPI_CONF) {-}


```table
---
width:
  - 0.2
  - 0.5
header: True
# inline markdown
markdown: True
include: data/register6.csv
---
```

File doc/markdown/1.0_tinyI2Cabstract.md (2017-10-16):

# TinyI2C プロジェクトの概要

**_TinyI2C_** はmbed^TM^ 互換のマイクロコントローラで小さなUART-I^2^C変換モジュールの
ハードウェアとソフトウェアを設計するプロジェクトです。**`TinyI2C`** モジュールは
UART^[<https://ja.wikipedia.org/wiki/UART>] で送られるコマンドパケットを変換し
I^2^CやSPI通信したり、個別にプルアップ／プルダウンを指定可能なGPIOの読み書きを行います。

## プロジェクトディレクトリツリー

<!-- ```{.plantuml im_out="img" caption="Directory Tree"}
@startsalt
{
  {T
  ""/"" (プロジェクトルート)
  + ""doc/""（ドキュメントフォルダ）
  ++ ""data/""（スクリーンショットなど）
  + ""mbed/""（ファームウェアソースコード（mbed用））
  + ""gui/""（GUIビルド用pythonソースコードとQt5プロジェクトファイル）
  + ""pcb/""（tinyI2Cハードウェアの設計ファイル）
  ++ ""tinyI2C_P/""（ガーバデータ）
  + ""python/""（pythonライブラリ）
  }
}
@endsalt
```
-->

```
(プロジェクトルート)
|
|---doc（ドキュメントフォルダ）
|   '---data（スクリーンショットなど）
|---mbed（ファームウェアソースコード（mbed用））
|---gui（GUIビルド用pythonソースコードとQt5プロジェクトファイル）
|---pcb（tinyI2Cハードウェアの設計ファイル）
|   '---tinyI2C_P（ガーバデータ）
'---python（pythonライブラリ）
```

## 特徴
- FTDI^[<http://www.ftdichip.com/>] のUSBシリアル変換ケーブル^[TODO: TinyI2Cのみ]
  またはmbedコントローラでホストのPCにつなぎます。PCからはただのUSBシリアルポートに見えます。
    - 最大115200ボーのUART通信をサポート
- 最大４チャネルの I^2^Cポートを持ち、それぞれのクロックスピードを独立に変更できます。
- SPIポートをひとつ持ち、ワード長とクロックスピードを変更できます。
- 最大２つの８ビット汎用IOポート

## 動作要件
### ソフトウェア
以下のソフトウェアをインストールしたコンピュータが必要です。
条件を満たせばラズパイでも動くと思います：

- Python 3.5^[<https://www.python.org/>]
    - もともと2.7用に開発してましたが、Python3系で動くようにライブラリ・GUIとも移植しました。
      移植後は3.5のみ動作確認してます。
- PySerialライブラリ
    - PIP(Pythonのパッケージインストーラ)で入手できます
    - `$ pip3 install pyserial`{.sh}
- **_Windowsのみ_** mbedインタフェース用のドライバ[^mbed_Serial_port_driver] を
  インストールする必要があります。

<!--  -->
[^mbed_Serial_port_driver]: <http://developer.mbed.org/handbook/Windows-serial-configuration>

### ハードウェア
以下のいずれかのマイクロコントローラを搭載したマイコンボードが必要です：

- LPC824
    - <https://developer.mbed.org/platforms/LPCXpresso824-MAX/>
    - <https://developer.mbed.org/platforms/Switch-Science-mbed-LPC824/>
- LPC11U35
    - <https://developer.mbed.org/platforms/EA-LPC11U35/>
        - **秋月的互換品が1/3程度の値段で売られてます** ：<http://akizukidenshi.com/catalog/g/gK-12144/>
    - <https://developer.mbed.org/platforms/TG-LPC11U35-501/>
- LPC1768
    - <https://developer.mbed.org/platforms/mbed-LPC1768/>

## 使い方
<!-- ### コンソールから使う場合 -->
1. mbedマイコンにファームウェアを書き込む
1. pythonコンソールを起動し、ライブラリをインポートする<!-- 2. ![TODO: console image]() -->
1. **これでもう使えます！**

## デモプログラム
コンソールでpythonディレクトリに移動して **`$ python test.py`{.sh}** を試してみてください。

```
usage: test.py [-h] [--port PORT] [--baud BAUD]
```

## GUIデモ
GUIのソースコードは **`gui`** ディレクトリに用意されています。
 いまのところ、_自力でコンパイル_ してもらう形になっています。

### GUIコンパイル要件
- PyQt5
    - **_Windowsのみ_** OSに合わせてインストーラをダウンロードする形態のようです
- pyinstaller

### GUIのコンパイルと実行
プロジェクトのルートディレクトリで
```{.sh }
$ make gui
```
とすると`dist`と`build`ディレクトリが作られます。実行可能ファイルは`dist`に置かれます。
```{.sh }
$ dist/TinyI2C
```
で実行できます。筆者の環境ではWindows/Linux/OSXとも動作確認できていますが、うまくいかないときは
```{.sh }
$ python gui/main.py
```
と実行するとなにかヒントが出るかもしれません。

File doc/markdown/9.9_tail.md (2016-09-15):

\newpage
\thispagestyle{empty}
\checkoddpage\ifoddpage\cleardoublepage\else\clearpage\fi
\thispagestyle{empty}
\vspace*{100ex}

| NXPのICでNXPのICをエミュレートしてみた本 |
|:----------------------------------------:|
|                  KY技研                  |
|               @\_K4ZUKI\_                |
|       Markdown x Pandoc x \XeLaTeX       |
|       Revision 1.0 / C91 / (hash)        |
|        秋葉原キンコーズで印刷製本        |

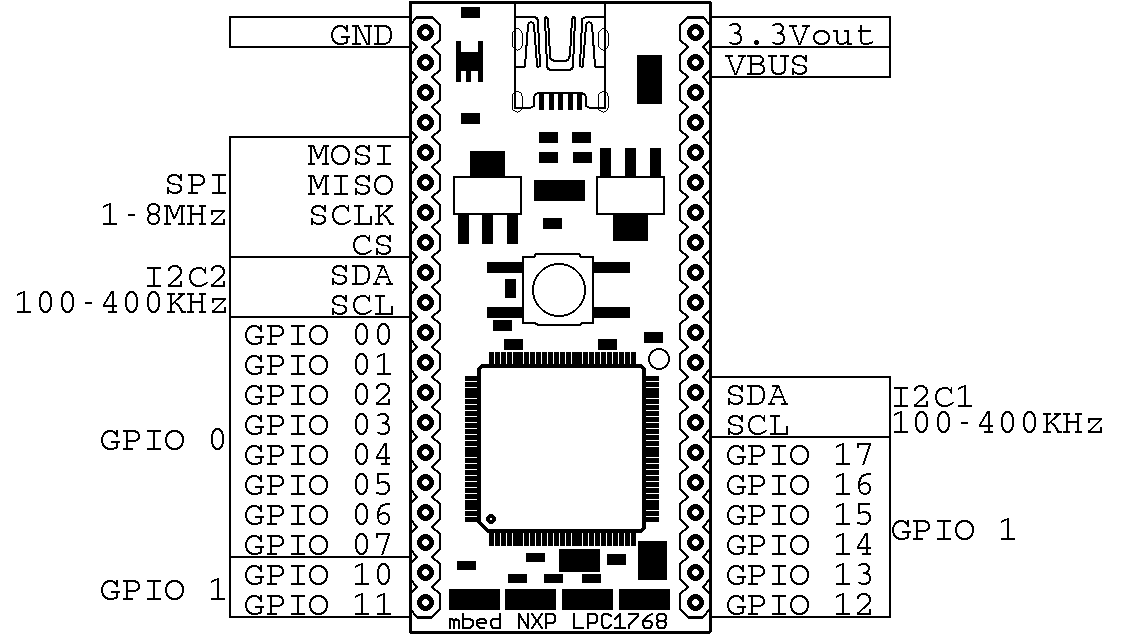
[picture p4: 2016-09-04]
doc/LPC1768_pin.png

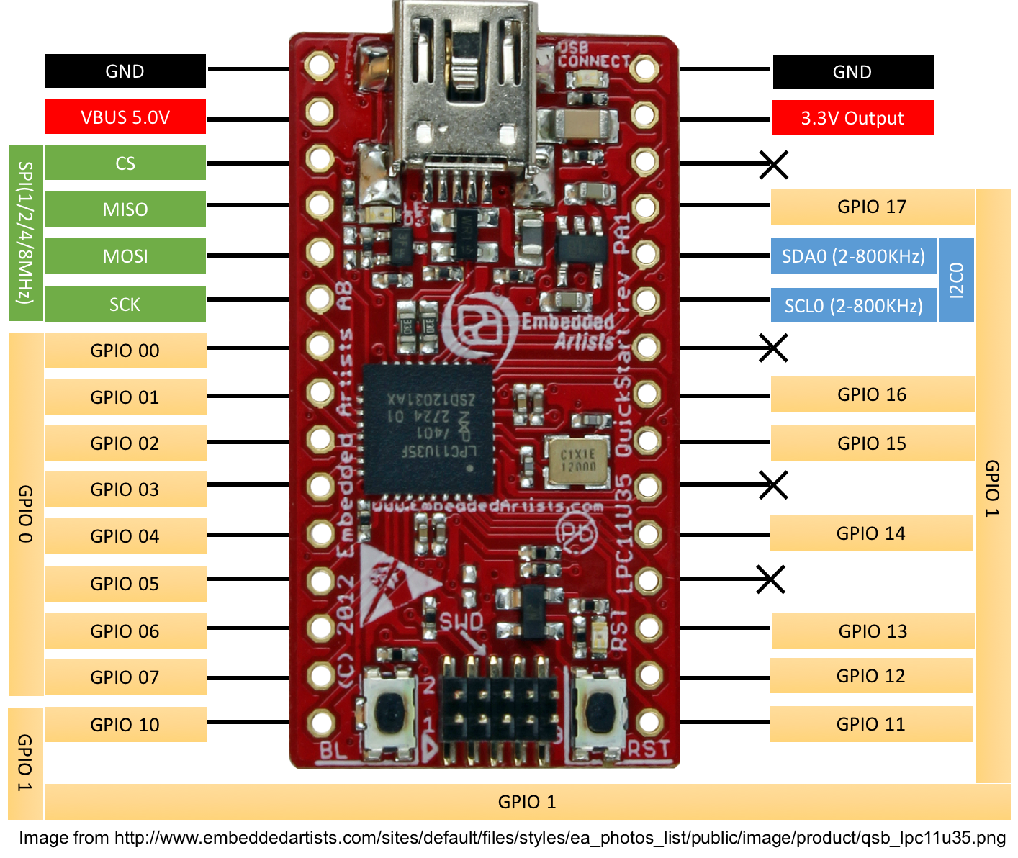
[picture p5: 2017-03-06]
doc/images/TinyI2C_11U35.png

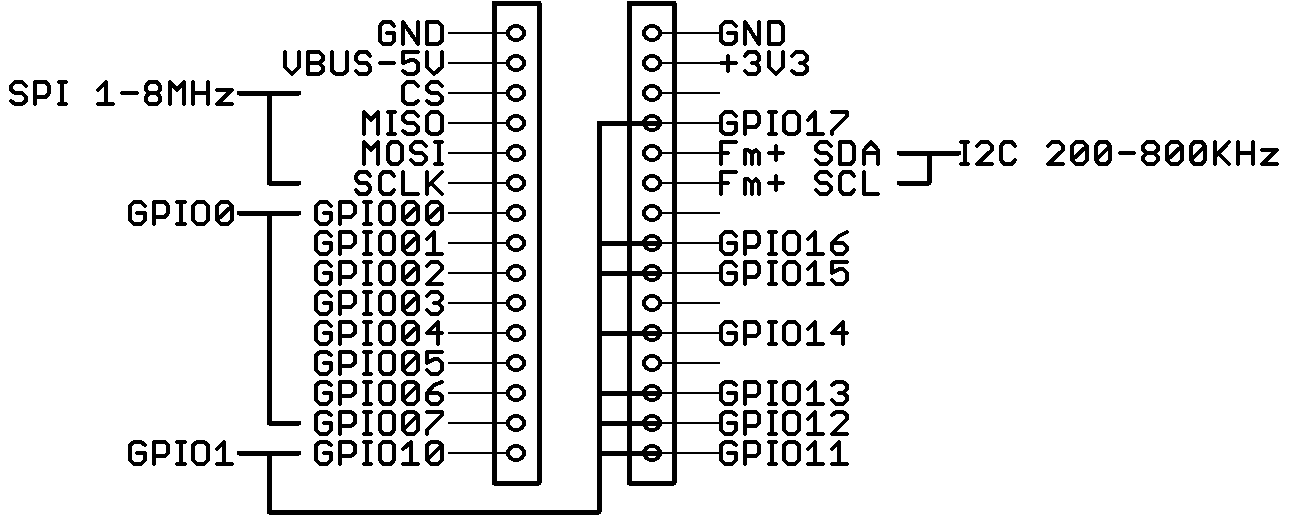
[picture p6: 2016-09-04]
doc/LPC11U35_pin.png

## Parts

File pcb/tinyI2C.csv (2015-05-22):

Qty | Value | Device | Package | Parts | Description
4 | 0.1u/1005 | C_PAD_PAD_1005 | C0402 | C1, C2, C6, C7 | SMD CAPACITOR : PAD - PAD
8 | 10k/1005 | R_US_PAD_PAD_1005 | C0402 | R3, R4, R5, R6, R7, R8, R9, R10 | R_US_PAD_PAD : SMD R PAD is NTH-NTH
3 | 10u/1005 | C_PAD_PAD_1005 | C0402 | C3, C4, C5 | SMD CAPACITOR : PAD - PAD
1 | 12MHz | XTAL-4-3225 | NX3225 | Q1 | Classic 4-pin 3.2 x 2.5mm crystal
2 | 18p/1005 | C_PAD_PAD_1005 | C0402 | C8, C9 | SMD CAPACITOR : PAD - PAD
2 | 220/1005 | R_US_PAD_PAD_1005 | C0402 | R1, R2 | R_US_PAD_PAD : SMD R PAD is NTH-NTH
2 | 74LVC1G125DCK | 74LVC1G125DCK | SC70-5 | IC1, IC2 | Single Bus Buffer Gate with 3-State Output
1 | IC_LDO_MIC5355 | IC_LDO_MIC5355 | IC_08_0.65_160MIL | IC3
1 | LPC824M201JHI33 | LPC824M201JHI33 | HVQFN33 | U1
2 | TPB1,27 | TPB1,27 | B1,27 | TP3, TP7 | Test pad
3 | TPTP07R | TPTP07R | TP07R | TP1, TP2, TP6 | Test pad
2 | TPTP10R | TPTP10R | TP10R | TP4, TP5 | Test pad
3 | TSW-102-02-S-S | TSW-102-02-S-S | TSW-102-02-S-S | X4, X5, X6 | THROUGH-HOLE .025inch SQ POST HEADER
1 | TSW-106-02-S-S-RA | TSW-106-02-S-S-RA | TSW-106-02-S-S-RA | X3 | THROUGH-HOLE .025inch SQ POST HEADER
2 | TSW-112-02-S-S | TSW-112-02-S-S | TSW-112-02-S-S | X1, X2 | THROUGH-HOLE .025inch SQ POST HEADER

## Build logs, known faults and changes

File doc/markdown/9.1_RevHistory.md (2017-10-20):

# 更新履歴 {.unnumbered}
## Revision 1.0(技術書典３) {.unnumbered}
- 最初の発行。表紙に画像を埋め込むスタイルにしてみた
- C91に出す計画もあったけどずれ込みましたとさ
- 日本語文書めんどい。
    - 英語で書き上げたREADMEを日本語に書き換える作業はつらいですw 表の内容とか。
- 次はPyPiにパッケージ登録したいですね。知り合いにやり方聞いてみます。流儀がコロコロ変わるらしいので注意しないと

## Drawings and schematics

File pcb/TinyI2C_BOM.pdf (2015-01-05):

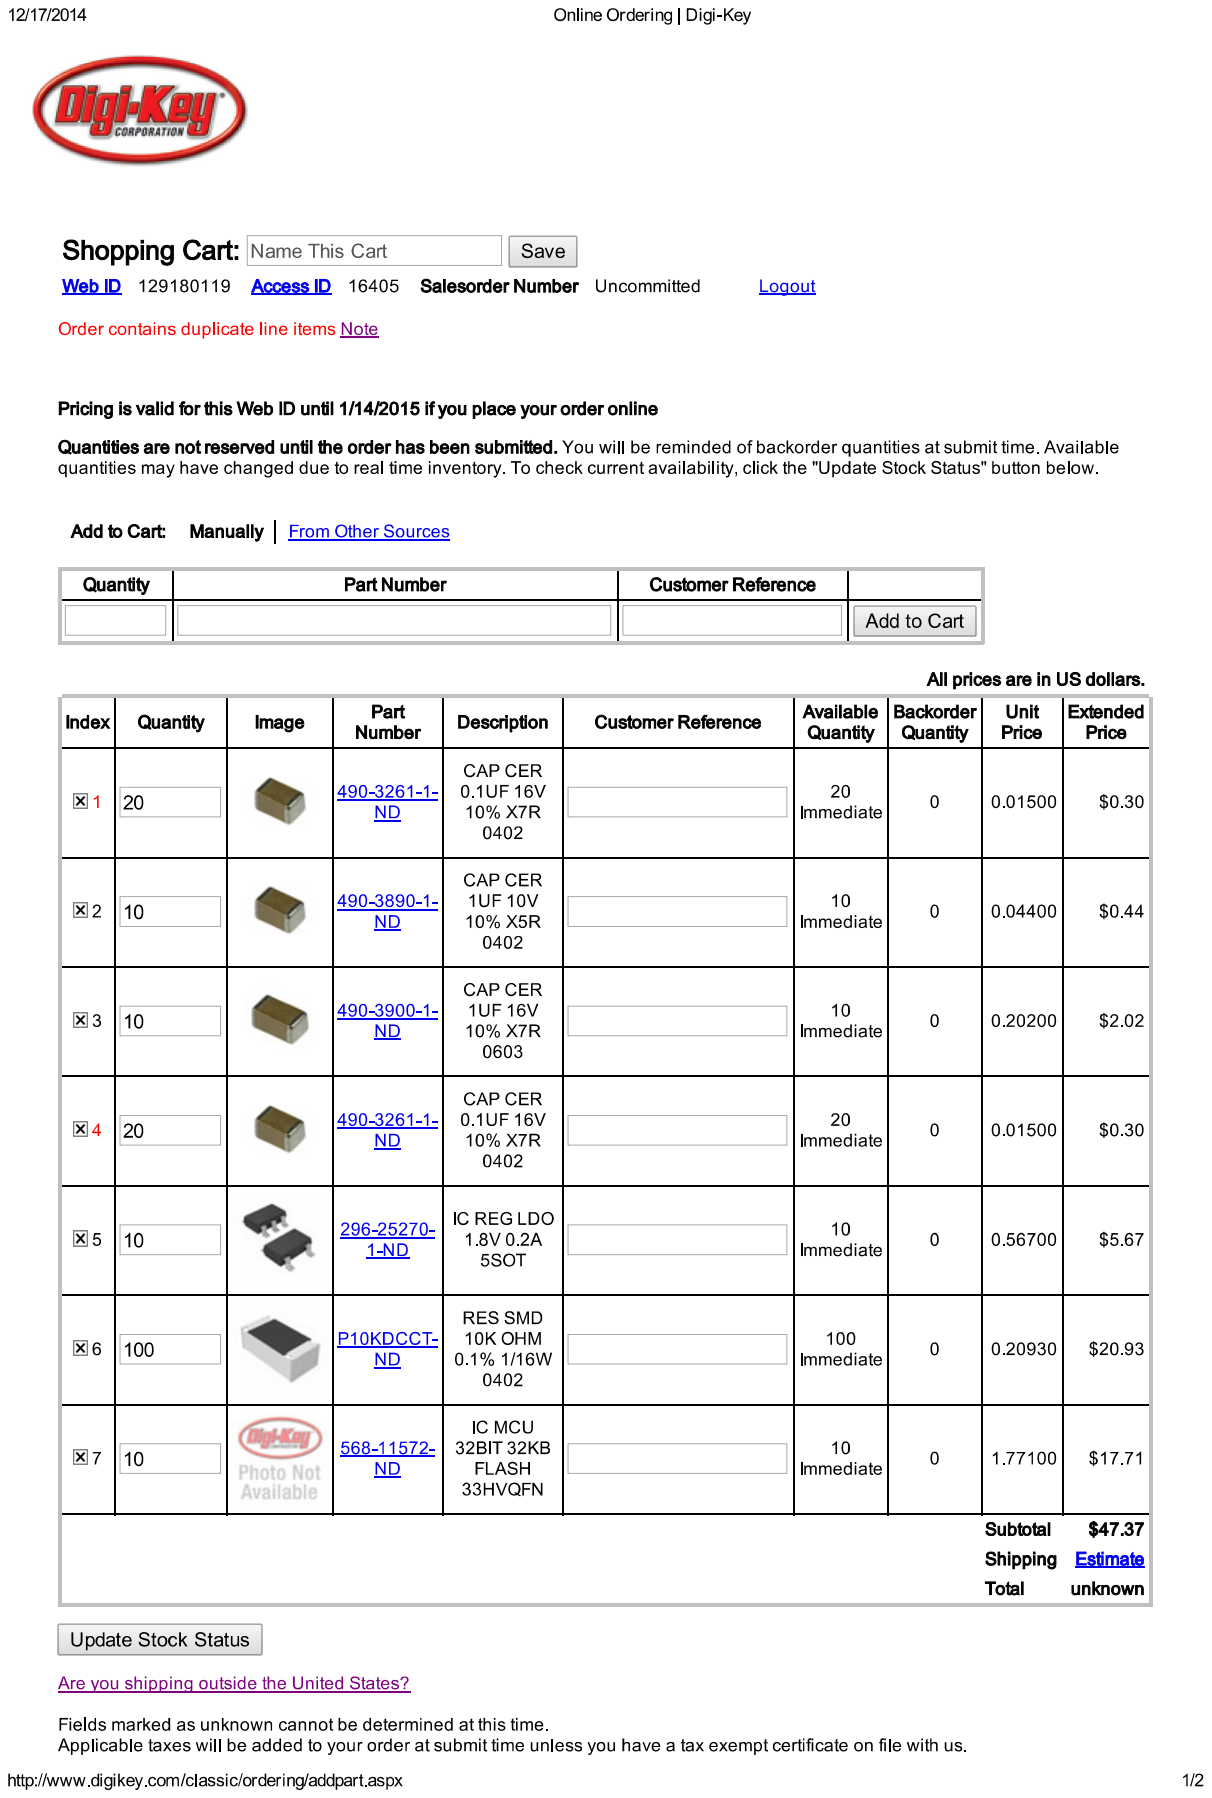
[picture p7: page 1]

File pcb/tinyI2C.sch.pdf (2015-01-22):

A

A

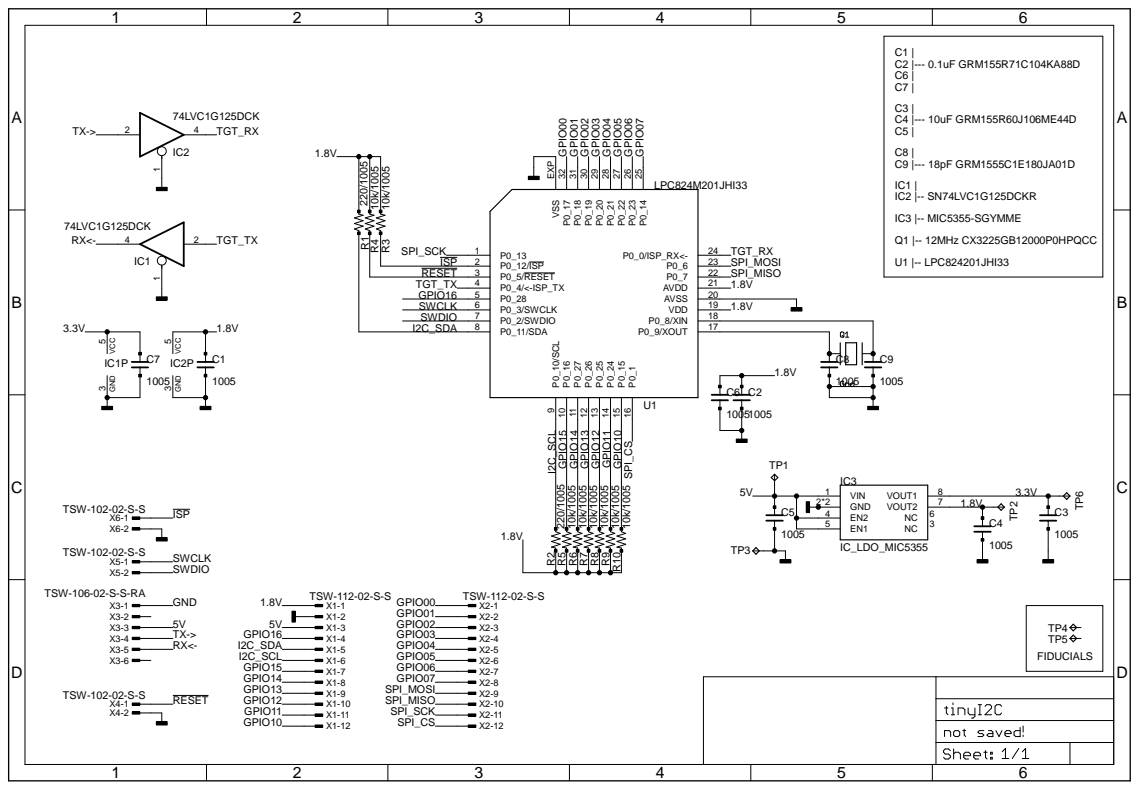
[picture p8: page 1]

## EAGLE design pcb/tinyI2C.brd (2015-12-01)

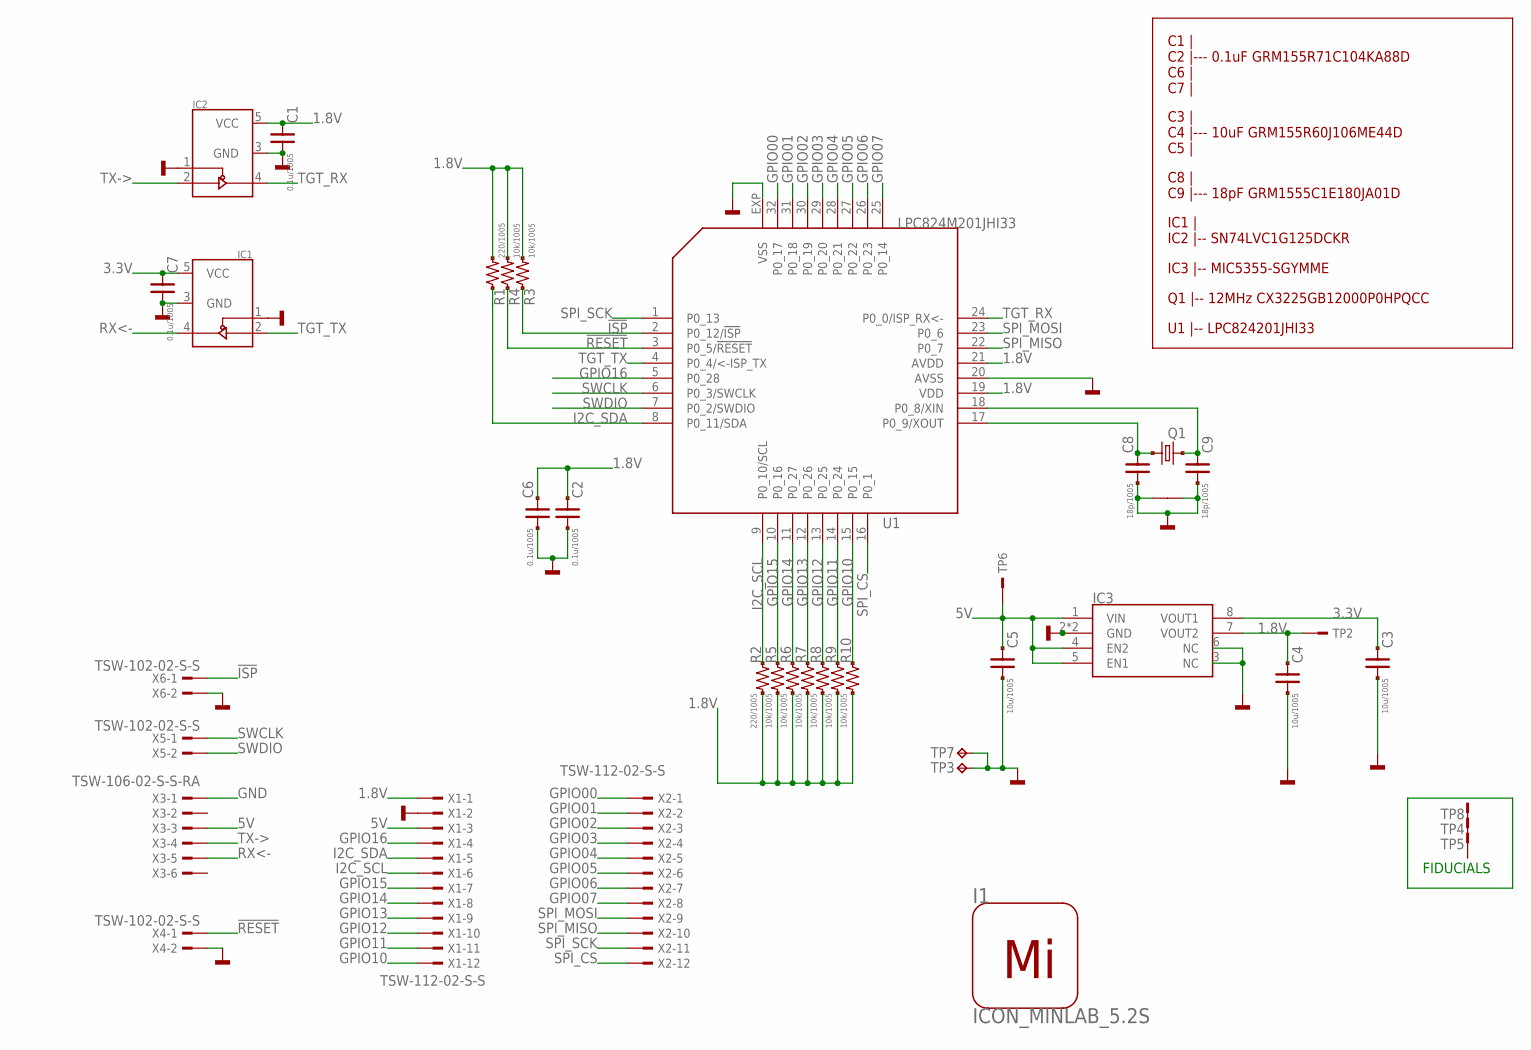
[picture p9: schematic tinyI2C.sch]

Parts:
C1, C2, C6, C7: 0.1u/1005; C0402
C3, C4, C5: 10u/1005; C0402
C8, C9: 18p/1005; C0402
I1: ICON_MINLAB_5.2S; ICON_MINLAB_5.2MM
IC1, IC2: 74LVC1G125_SC70; IC_05_0.635_40MIL
IC3: IC_LDO_MIC5355_3.3/1.8; IC_08_0.65_160MIL_EP
Q1: CRYSTAL4_12M_3225; CLOCK_3225
R1, R2: 220/1005; C0402
R3, R4, R5, R6, R7, R8, R9, R10: 10k/1005; C0402
TP2, TP6: TESTPAD; TP06RECT
TP3, TP7: TPTP14R; TP14R
TP4, TP5, TP8: TESTPAD_F; FIDUCIAL
U1: LPC824M201JHI33; HVQFN33
X1, X2: TSW-112-02-S-S
X3: TSW-106-02-S-S-RA
X4, X5, X6: TSW-102-02-S-S

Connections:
1.8V: C1.1, C2.1, C4.1, C6.1, IC2.5 (VCC), IC3.7 (VOUT2), R1.2, R2.2, R3.2, R4.2, R5.2, R6.2, R7.2, R8.2, R9.2, R10.2, TP2.TP, U1.19 (VDD), U1.21 (AVDD), X1.1
3.3V: C3.1, C7.1, IC1.5 (VCC), IC3.8 (VOUT1)
5V: C5.1, IC3.1 (VIN), IC3.4 (EN2), IC3.5 (EN1), TP6.TP, X1.3, X3.3
!ISP!: R3.1, U1.2 (P0_12/!ISP!), X6.1
!RESET!: R4.1, U1.3 (P0_5/!RESET!), X4.1
GND: C1.2, C2.2, C3.2, C4.2, C5.2, C6.2, C7.2, C8.2, C9.2, IC1.1 (!OE!), IC1.3 (GND), IC2.1 (!OE!), IC2.3 (GND), IC3.2 (GND), IC3.3 (NC), IC3.6 (NC), IC3.EXP (GND), Q1.2, Q1.4, TP3.TP, TP7.TP, U1.20 (AVSS), U1.EXP (VSS), X1.2, X3.1, X4.2, X6.2
GPIO00: U1.32 (P0_17), X2.1
GPIO01: U1.31 (P0_18), X2.2
GPIO02: U1.30 (P0_19), X2.3
GPIO03: U1.29 (P0_20), X2.4
GPIO04: U1.28 (P0_21), X2.5
GPIO05: U1.27 (P0_22), X2.6
GPIO06: U1.26 (P0_23), X2.7
GPIO07: U1.25 (P0_14), X2.8
GPIO10: R10.1, U1.15 (P0_15), X1.12
GPIO11: R9.1, U1.14 (P0_24), X1.11
GPIO12: R8.1, U1.13 (P0_25), X1.10
GPIO13: R7.1, U1.12 (P0_26), X1.9
GPIO14: R6.1, U1.11 (P0_27), X1.8
GPIO15: R5.1, U1.10 (P0_16), X1.7
GPIO16: U1.5 (P0_28), X1.4
I2C_SCL: R2.1, U1.9 (P0_10/SCL), X1.6
I2C_SDA: R1.1, U1.8 (P0_11/SDA), X1.5
unnamed: C8.1, Q1.1, U1.17 (P0_9/XOUT)
unnamed: C9.1, Q1.3 (2), U1.18 (P0_8/XIN)
RX<-: IC1.4 (Y), X3.5
SPI_CS: U1.16 (P0_1), X2.12
SPI_MISO: U1.22 (P0_7), X2.10
SPI_MOSI: U1.23 (P0_6), X2.9
SPI_SCK: U1.1 (P0_13), X2.11
SWCLK: U1.6 (P0_3/SWCLK), X5.1
SWDIO: U1.7 (P0_2/SWDIO), X5.2
TGT_RX: IC2.4 (Y), U1.24 (P0_0/ISP_RX<-)
TGT_TX: IC1.2 (A), U1.4 (P0_4/<-ISP_TX)
TX->: IC2.2 (A), X3.4

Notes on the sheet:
FIDUCIALS
C1 | C2 |--- 0.1uF GRM155R71C104KA88D C6 | C7 |
C3 | C4 |--- 10uF GRM155R60J106ME44D C5 |
IC1 | IC2 |-- SN74LVC1G125DCKR
IC3 |-- MIC5355-SGYMME
U1 |-- LPC824201JHI33
C8 | C9 |--- 18pF GRM1555C1E180JA01D
Q1 |-- 12MHz CX3225GB12000P0HPQCC

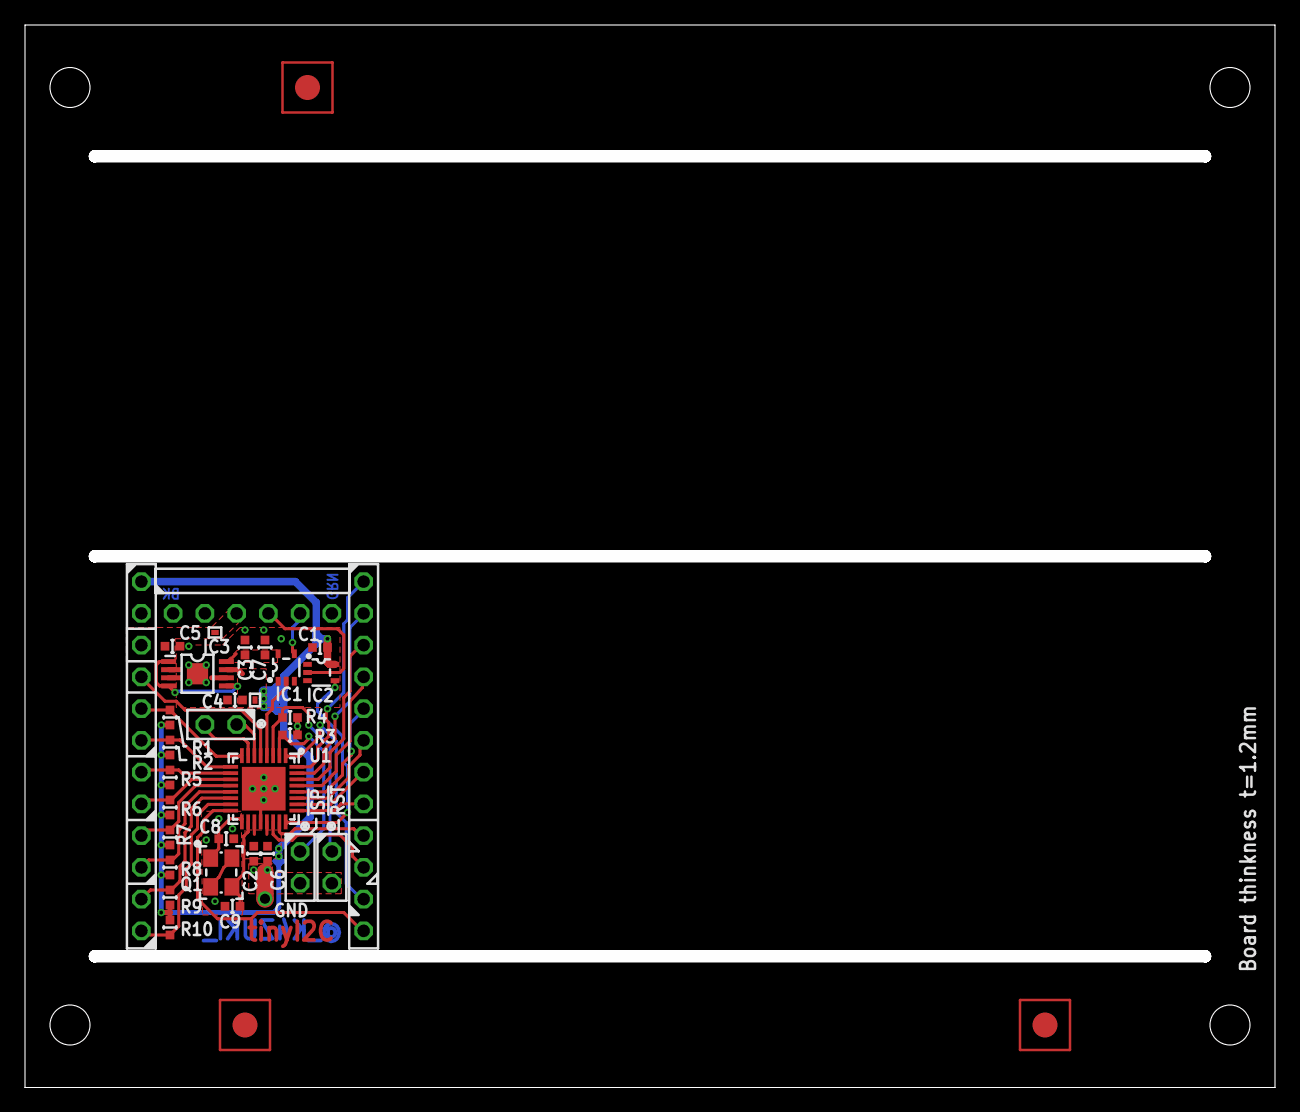
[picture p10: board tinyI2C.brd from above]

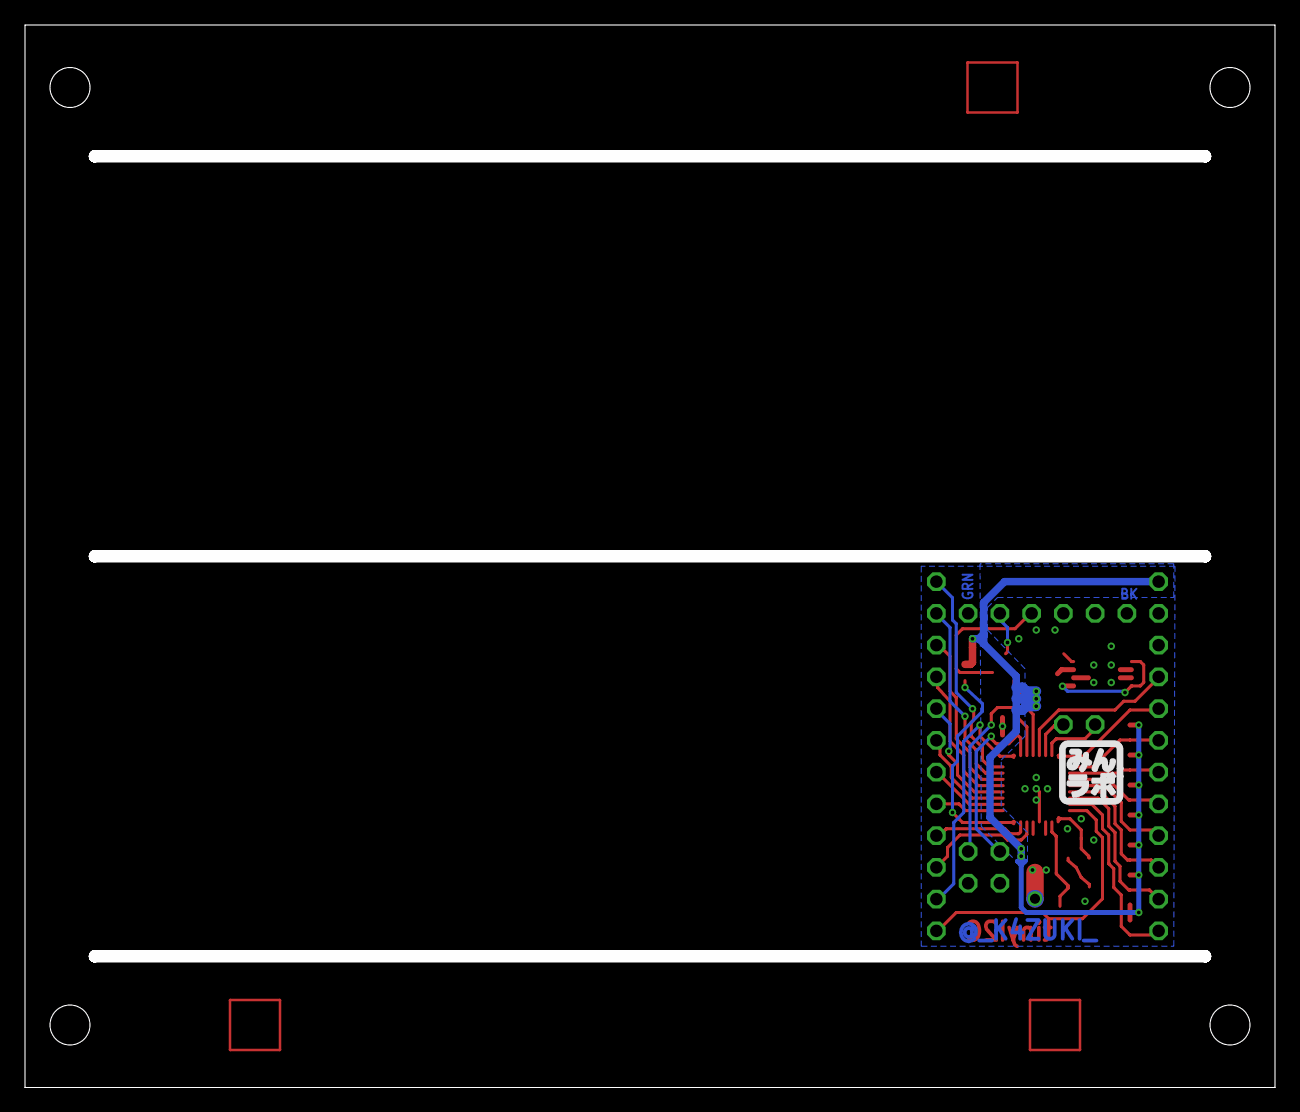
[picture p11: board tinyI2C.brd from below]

Board: 2 copper layers, 100.0 x 85.0 mm, 38 parts (2 on the bottom side), 35 nets.

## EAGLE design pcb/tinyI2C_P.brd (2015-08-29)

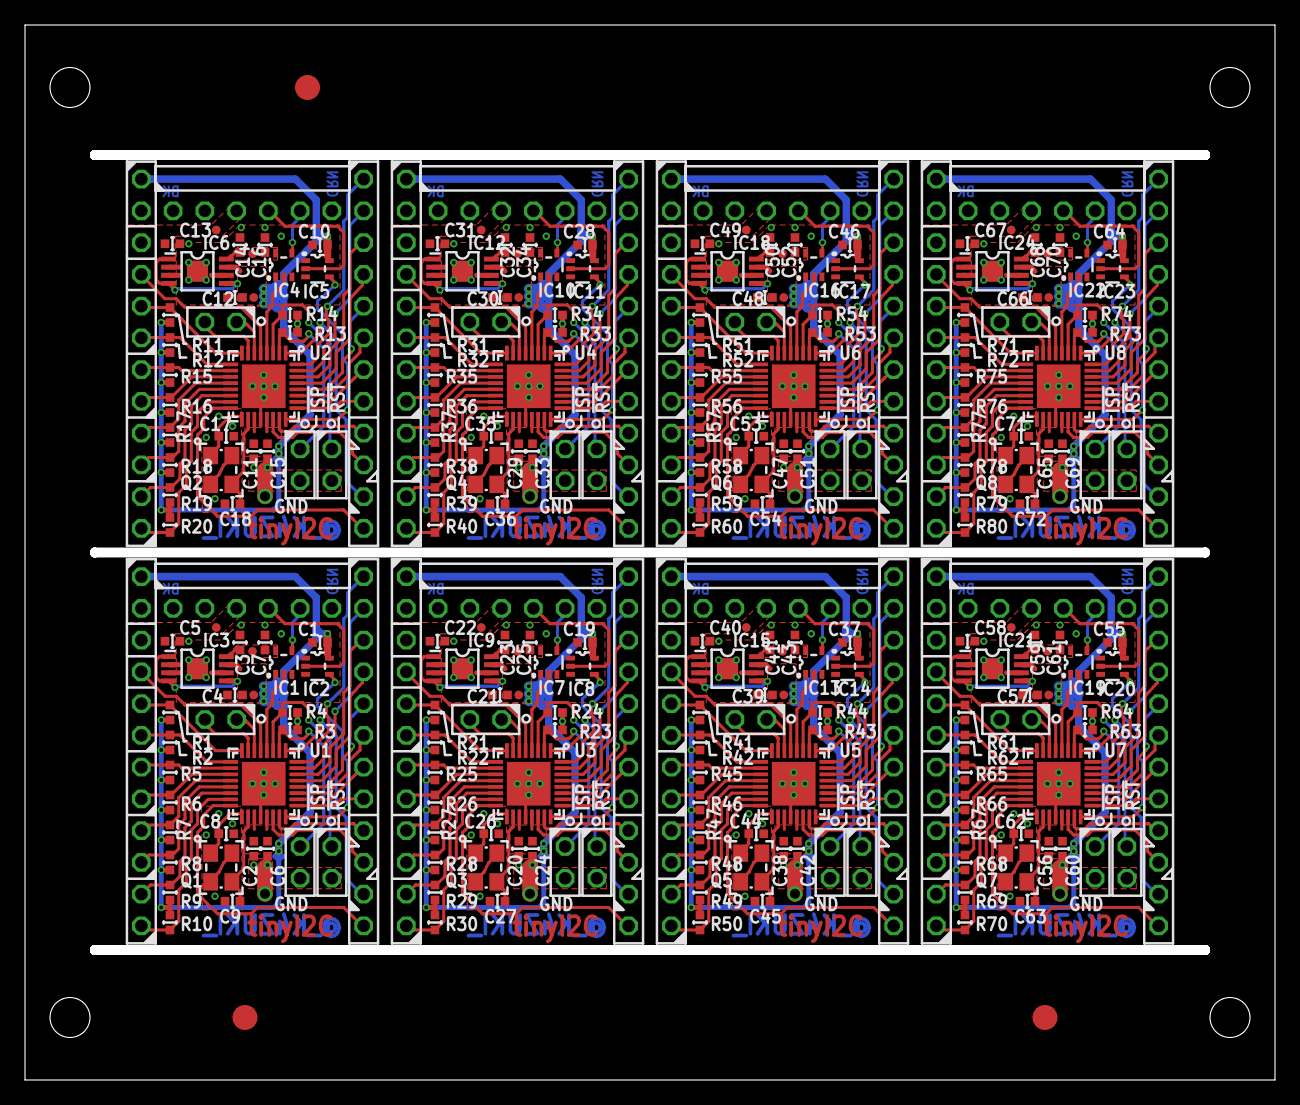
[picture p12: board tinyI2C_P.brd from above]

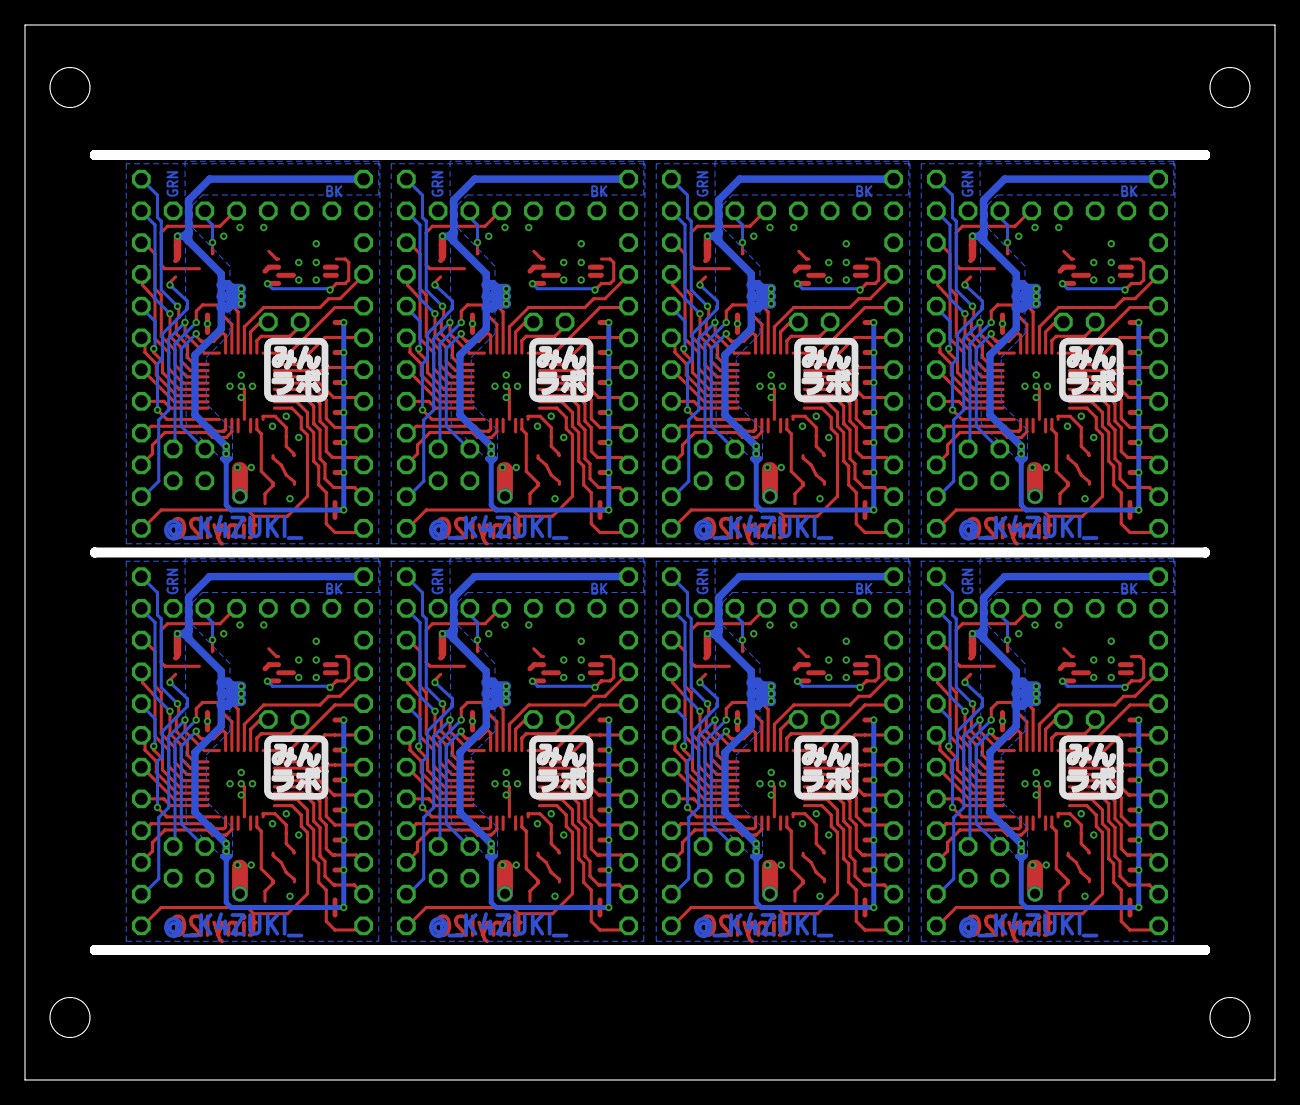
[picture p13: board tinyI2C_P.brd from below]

Board: 2 copper layers, 100.0 x 84.4 mm, 291 parts (16 on the bottom side), 280 nets.

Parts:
C1, C2, C6, C7, C10, C11, C15, C16, C19, C20, C24, C25, C28, C29, C33, C34, C37, C38, C42, C43, C46, C47, C51, C52, C55, C56, C60, C61, C64, C65, C69, C70: 0.1u/1005; C0402
C3, C4, C5, C12, C13, C14, C21, C22, C23, C30, C31, C32, C39, C40, C41, C48, C49, C50, C57, C58, C59, C66, C67, C68: 10u/1005; C0402
C8, C9, C17, C18, C26, C27, C35, C36, C44, C45, C53, C54, C62, C63, C71, C72: 18p/1005; C0402
I1, I2, I3, I4, I5, I6, I7, I8: ICON_MINLAB_5.2S; ICON_MINLAB_5.2MM
IC1, IC2, IC4, IC5, IC7, IC8, IC10, IC11, IC13, IC14, IC16, IC17, IC19, IC20, IC22, IC23: 74LVC1G125DCK; SC70-5
IC3, IC6, IC9, IC12, IC15, IC18, IC21, IC24: IC_LDO_MIC5355; IC_08_0.65_160MIL_EP
Q1, Q2, Q3, Q4, Q5, Q6, Q7, Q8: 12MHz; NX3225
R1, R2, R11, R12, R21, R22, R31, R32, R41, R42, R51, R52, R61, R62, R71, R72: 220/1005; C0402
R3, R4, R5, R6, R7, R8, R9, R10, R13, R14, R15, R16, R17, R18, R19, R20, R23, R24, R25, R26, R27, R28, R29, R30, R33, R34, R35, R36, R37, R38, R39, R40, R43, R44, R45, R46, R47, R48, R49, R50, R53, R54, R55, R56, R57, R58, R59, R60, R63, R64, R65, R66, R67, R68, R69, R70, R73, R74, R75, R76, R77, R78, R79, R80: 10k/1005; C0402
TP1, TP2, TP6, TP9, TP10, TP12, TP14, TP15, TP17, TP19, TP20, TP22, TP24, TP25, TP27, TP29, TP30, TP32, TP34, TP35, TP37, TP39, TP40, TP42: TPTP07R; TP07R
TP3, TP7, TP11, TP13, TP16, TP18, TP21, TP23, TP26, TP28, TP31, TP33, TP36, TP38, TP41, TP43: TPB1,27; B1,27
TP4, TP5, TP8: TPTP20R; TP20R
U1, U2, U3, U4, U5, U6, U7, U8: LPC824M201JHI33; HVQFN33
X1, X2, X8, X9, X14, X15, X20, X21, X26, X27, X32, X33, X38, X39, X44, X45: TSW-112-02-S-S
X3, X7, X13, X19, X25, X31, X37, X43: TSW-106-02-S-S-RA
X4, X5, X6, X10, X11, X12, X16, X17, X18, X22, X23, X24, X28, X29, X30, X34, X35, X36, X40, X41, X42, X46, X47, X48: TSW-102-02-S-S

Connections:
1.8V: C1.1, C2.1, C4.1, C6.1, IC2.5, IC3.7, R1.2, R2.2, R3.2, R4.2, R5.2, R6.2, R7.2, R8.2, R9.2, R10.2, TP2.TP, U1.19, U1.21, X1.1
1.8V1: C10.1, C11.1, C12.1, C15.1, IC5.5, IC6.7, R11.2, R12.2, R13.2, R14.2, R15.2, R16.2, R17.2, R18.2, R19.2, R20.2, TP10.TP, U2.19, U2.21, X8.1
1.8V2: C19.1, C20.1, C21.1, C24.1, IC8.5, IC9.7, R21.2, R22.2, R23.2, R24.2, R25.2, R26.2, R27.2, R28.2, R29.2, R30.2, TP15.TP, U3.19, U3.21, X14.1
1.8V3: C28.1, C29.1, C30.1, C33.1, IC11.5, IC12.7, R31.2, R32.2, R33.2, R34.2, R35.2, R36.2, R37.2, R38.2, R39.2, R40.2, TP20.TP, U4.19, U4.21, X20.1
1.8V4: C37.1, C38.1, C39.1, C42.1, IC14.5, IC15.7, R41.2, R42.2, R43.2, R44.2, R45.2, R46.2, R47.2, R48.2, R49.2, R50.2, TP25.TP, U5.19, U5.21, X26.1
1.8V5: C46.1, C47.1, C48.1, C51.1, IC17.5, IC18.7, R51.2, R52.2, R53.2, R54.2, R55.2, R56.2, R57.2, R58.2, R59.2, R60.2, TP30.TP, U6.19, U6.21, X32.1
1.8V6: C55.1, C56.1, C57.1, C60.1, IC20.5, IC21.7, R61.2, R62.2, R63.2, R64.2, R65.2, R66.2, R67.2, R68.2, R69.2, R70.2, TP35.TP, U7.19, U7.21, X38.1
1.8V7: C64.1, C65.1, C66.1, C69.1, IC23.5, IC24.7, R71.2, R72.2, R73.2, R74.2, R75.2, R76.2, R77.2, R78.2, R79.2, R80.2, TP40.TP, U8.19, U8.21, X44.1
3.3V: C3.1, C7.1, IC1.5, IC3.8, TP6.TP
3.3V1: C14.1, C16.1, IC4.5, IC6.8, TP12.TP
3.3V2: C23.1, C25.1, IC7.5, IC9.8, TP17.TP
3.3V3: C32.1, C34.1, IC10.5, IC12.8, TP22.TP
3.3V4: C41.1, C43.1, IC13.5, IC15.8, TP27.TP
3.3V5: C50.1, C52.1, IC16.5, IC18.8, TP32.TP
3.3V6: C59.1, C61.1, IC19.5, IC21.8, TP37.TP
3.3V7: C68.1, C70.1, IC22.5, IC24.8, TP42.TP
5V: C5.1, IC3.1, IC3.4, IC3.5, TP1.TP, X1.3, X3.3
5V1: C13.1, IC6.1, IC6.4, IC6.5, TP9.TP, X7.3, X8.3
5V2: C22.1, IC9.1, IC9.4, IC9.5, TP14.TP, X13.3, X14.3
5V3: C31.1, IC12.1, IC12.4, IC12.5, TP19.TP, X19.3, X20.3
5V4: C40.1, IC15.1, IC15.4, IC15.5, TP24.TP, X25.3, X26.3
5V5: C49.1, IC18.1, IC18.4, IC18.5, TP29.TP, X31.3, X32.3
5V6: C58.1, IC21.1, IC21.4, IC21.5, TP34.TP, X37.3, X38.3
5V7: C67.1, IC24.1, IC24.4, IC24.5, TP39.TP, X43.3, X44.3
!ISP!: R3.1, U1.2, X6.1
!ISP!1: R13.1, U2.2, X12.1
!ISP!2: R23.1, U3.2, X18.1
!ISP!3: R33.1, U4.2, X24.1
!ISP!4: R43.1, U5.2, X30.1
!ISP!5: R53.1, U6.2, X36.1
!ISP!6: R63.1, U7.2, X42.1
!ISP!7: R73.1, U8.2, X48.1
!RESET!: R4.1, U1.3, X4.1
!RESET!1: R14.1, U2.3, X10.1
!RESET!2: R24.1, U3.3, X16.1
!RESET!3: R34.1, U4.3, X22.1
!RESET!4: R44.1, U5.3, X28.1
!RESET!5: R54.1, U6.3, X34.1
!RESET!6: R64.1, U7.3, X40.1
!RESET!7: R74.1, U8.3, X46.1
GND: C1.2, C2.2, C3.2, C4.2, C5.2, C6.2, C7.2, C8.2, C9.2, IC1.1, IC1.3, IC2.1, IC2.3, IC3.2, IC3.3, IC3.6, IC3.EXP, Q1.2, Q1.4, TP3.TP, TP7.TP, U1.20, U1.EXP, X1.2, X3.1, X4.2, X6.2
GND1: C10.2, C11.2, C12.2, C13.2, C14.2, C15.2, C16.2, C17.2, C18.2, IC4.1, IC4.3, IC5.1, IC5.3, IC6.2, IC6.3, IC6.6, IC6.EXP, Q2.2, Q2.4, TP11.TP, TP13.TP, U2.20, U2.EXP, X7.1, X8.2, X10.2, X12.2
GND2: C19.2, C20.2, C21.2, C22.2, C23.2, C24.2, C25.2, C26.2, C27.2, IC7.1, IC7.3, IC8.1, IC8.3, IC9.2, IC9.3, IC9.6, IC9.EXP, Q3.2, Q3.4, TP16.TP, TP18.TP, U3.20, U3.EXP, X13.1, X14.2, X16.2, X18.2
GND3: C28.2, C29.2, C30.2, C31.2, C32.2, C33.2, C34.2, C35.2, C36.2, IC10.1, IC10.3, IC11.1, IC11.3, IC12.2, IC12.3, IC12.6, IC12.EXP, Q4.2, Q4.4, TP21.TP, TP23.TP, U4.20, U4.EXP, X19.1, X20.2, X22.2, X24.2
GND4: C37.2, C38.2, C39.2, C40.2, C41.2, C42.2, C43.2, C44.2, C45.2, IC13.1, IC13.3, IC14.1, IC14.3, IC15.2, IC15.3, IC15.6, IC15.EXP, Q5.2, Q5.4, TP26.TP, TP28.TP, U5.20, U5.EXP, X25.1, X26.2, X28.2, X30.2
GND5: C46.2, C47.2, C48.2, C49.2, C50.2, C51.2, C52.2, C53.2, C54.2, IC16.1, IC16.3, IC17.1, IC17.3, IC18.2, IC18.3, IC18.6, IC18.EXP, Q6.2, Q6.4, TP31.TP, TP33.TP, U6.20, U6.EXP, X31.1, X32.2, X34.2, X36.2
GND6: C55.2, C56.2, C57.2, C58.2, C59.2, C60.2, C61.2, C62.2, C63.2, IC19.1, IC19.3, IC20.1, IC20.3, IC21.2, IC21.3, IC21.6, IC21.EXP, Q7.2, Q7.4, TP36.TP, TP38.TP, U7.20, U7.EXP, X37.1, X38.2, X40.2, X42.2
GND7: C64.2, C65.2, C66.2, C67.2, C68.2, C69.2, C70.2, C71.2, C72.2, IC22.1, IC22.3, IC23.1, IC23.3, IC24.2, IC24.3, IC24.6, IC24.EXP, Q8.2, Q8.4, TP41.TP, TP43.TP, U8.20, U8.EXP, X43.1, X44.2, X46.2, X48.2
GPIO00: U1.32, X2.1
GPIO01: U1.31, X2.2
GPIO02: U1.30, X2.3
GPIO03: U1.29, X2.4
GPIO04: U1.28, X2.5
GPIO05: U1.27, X2.6
GPIO06: U1.26, X2.7
GPIO07: U1.25, X2.8
GPIO08: U2.5, X8.4
GPIO09: R15.1, U2.10, X8.7
GPIO10: R10.1, U1.15, X1.12
GPIO11: R9.1, U1.14, X1.11
GPIO12: R8.1, U1.13, X1.10
GPIO13: R7.1, U1.12, X1.9
GPIO14: R6.1, U1.11, X1.8
GPIO15: R5.1, U1.10, X1.7
GPIO16: U1.5, X1.4
GPIO17: R16.1, U2.11, X8.8
GPIO18: R17.1, U2.12, X8.9
GPIO19: R18.1, U2.13, X8.10
GPIO20: R19.1, U2.14, X8.11
GPIO21: R20.1, U2.15, X8.12
GPIO22: U2.25, X9.8
GPIO23: U2.26, X9.7
GPIO24: U2.27, X9.6
GPIO25: U2.28, X9.5
GPIO26: U2.29, X9.4
GPIO27: U2.30, X9.3
GPIO28: U2.31, X9.2
GPIO29: U2.32, X9.1
GPIO30: U3.5, X14.4
GPIO31: R25.1, U3.10, X14.7
GPIO32: R26.1, U3.11, X14.8
GPIO33: R27.1, U3.12, X14.9
GPIO34: R28.1, U3.13, X14.10
GPIO35: R29.1, U3.14, X14.11
GPIO36: R30.1, U3.15, X14.12
GPIO37: U3.25, X15.8
GPIO38: U3.26, X15.7
GPIO39: U3.27, X15.6
GPIO40: U3.28, X15.5
GPIO41: U3.29, X15.4
GPIO42: U3.30, X15.3
GPIO43: U3.31, X15.2
GPIO44: U3.32, X15.1
GPIO45: U4.5, X20.4
GPIO46: R35.1, U4.10, X20.7
GPIO47: R36.1, U4.11, X20.8
GPIO48: R37.1, U4.12, X20.9
GPIO49: R38.1, U4.13, X20.10
GPIO50: R39.1, U4.14, X20.11
GPIO51: R40.1, U4.15, X20.12
GPIO52: U4.25, X21.8
GPIO53: U4.26, X21.7
GPIO54: U4.27, X21.6
GPIO55: U4.28, X21.5
GPIO56: U4.29, X21.4
GPIO57: U4.30, X21.3
GPIO58: U4.31, X21.2
GPIO59: U4.32, X21.1
GPIO60: U5.5, X26.4
GPIO61: R45.1, U5.10, X26.7
GPIO62: R46.1, U5.11, X26.8
GPIO63: R47.1, U5.12, X26.9
GPIO64: R48.1, U5.13, X26.10
GPIO65: R49.1, U5.14, X26.11
GPIO66: R50.1, U5.15, X26.12
GPIO67: U5.25, X27.8
GPIO68: U5.26, X27.7
GPIO69: U5.27, X27.6
GPIO70: U5.28, X27.5
GPIO71: U5.29, X27.4
GPIO72: U5.30, X27.3
GPIO73: U5.31, X27.2
GPIO74: U5.32, X27.1
GPIO75: U6.5, X32.4
GPIO76: R55.1, U6.10, X32.7
GPIO77: R56.1, U6.11, X32.8
GPIO78: R57.1, U6.12, X32.9
GPIO79: R58.1, U6.13, X32.10
GPIO80: R59.1, U6.14, X32.11
GPIO81: R60.1, U6.15, X32.12
GPIO82: U6.25, X33.8
GPIO83: U6.26, X33.7
GPIO84: U6.27, X33.6
GPIO85: U6.28, X33.5
GPIO86: U6.29, X33.4
GPIO87: U6.30, X33.3
GPIO88: U6.31, X33.2
GPIO89: U6.32, X33.1
GPIO90: U7.5, X38.4
GPIO91: R65.1, U7.10, X38.7
GPIO92: R66.1, U7.11, X38.8
GPIO93: R67.1, U7.12, X38.9
GPIO94: R68.1, U7.13, X38.10
GPIO95: R69.1, U7.14, X38.11
GPIO96: R70.1, U7.15, X38.12
GPIO97: U7.25, X39.8
GPIO98: U7.26, X39.7
GPIO99: U7.27, X39.6
GPIO100: U7.28, X39.5
GPIO101: U7.29, X39.4
GPIO102: U7.30, X39.3
GPIO103: U7.31, X39.2
GPIO104: U7.32, X39.1
GPIO105: U8.5, X44.4
GPIO106: R75.1, U8.10, X44.7
GPIO107: R76.1, U8.11, X44.8
GPIO108: R77.1, U8.12, X44.9
GPIO109: R78.1, U8.13, X44.10
GPIO110: R79.1, U8.14, X44.11
GPIO111: R80.1, U8.15, X44.12
GPIO112: U8.25, X45.8
GPIO113: U8.26, X45.7
GPIO114: U8.27, X45.6
GPIO115: U8.28, X45.5
GPIO116: U8.29, X45.4
GPIO117: U8.30, X45.3
GPIO118: U8.31, X45.2
GPIO119: U8.32, X45.1
I2C_SCL: R2.1, U1.9, X1.6
I2C_SCL1: R12.1, U2.9, X8.6
I2C_SCL2: R22.1, U3.9, X14.6
I2C_SCL3: R32.1, U4.9, X20.6
I2C_SCL4: R42.1, U5.9, X26.6
I2C_SCL5: R52.1, U6.9, X32.6
I2C_SCL6: R62.1, U7.9, X38.6
I2C_SCL7: R72.1, U8.9, X44.6
I2C_SDA: R1.1, U1.8, X1.5
I2C_SDA1: R11.1, U2.8, X8.5
I2C_SDA2: R21.1, U3.8, X14.5
I2C_SDA3: R31.1, U4.8, X20.5
I2C_SDA4: R41.1, U5.8, X26.5
I2C_SDA5: R51.1, U6.8, X32.5
I2C_SDA6: R61.1, U7.8, X38.5
I2C_SDA7: R71.1, U8.8, X44.5
unnamed: C8.1, Q1.1, U1.17
unnamed: C17.1, Q2.1, U2.17
unnamed: C9.1, Q1.3, U1.18
unnamed: C18.1, Q2.3, U2.18
unnamed: C26.1, Q3.1, U3.17
unnamed: C27.1, Q3.3, U3.18
unnamed: C35.1, Q4.1, U4.17
unnamed: C36.1, Q4.3, U4.18
unnamed: C44.1, Q5.1, U5.17
unnamed: C45.1, Q5.3, U5.18
unnamed: C53.1, Q6.1, U6.17
unnamed: C54.1, Q6.3, U6.18
unnamed: C62.1, Q7.1, U7.17
unnamed: C63.1, Q7.3, U7.18
unnamed: C71.1, Q8.1, U8.17
unnamed: C72.1, Q8.3, U8.18
RX<-: IC1.4, X3.5
RX<-1: IC4.4, X7.5
RX<-2: IC7.4, X13.5
RX<-3: IC10.4, X19.5
RX<-4: IC13.4, X25.5
RX<-5: IC16.4, X31.5
RX<-6: IC19.4, X37.5
RX<-7: IC22.4, X43.5
SPI_CS: U1.16, X2.12
SPI_CS1: U2.16, X9.12
SPI_CS2: U3.16, X15.12
SPI_CS3: U4.16, X21.12
SPI_CS4: U5.16, X27.12
SPI_CS5: U6.16, X33.12
SPI_CS6: U7.16, X39.12
SPI_CS7: U8.16, X45.12
SPI_MISO: U1.22, X2.10
SPI_MISO1: U2.22, X9.10
SPI_MISO2: U3.22, X15.10
SPI_MISO3: U4.22, X21.10
SPI_MISO4: U5.22, X27.10
SPI_MISO5: U6.22, X33.10
SPI_MISO6: U7.22, X39.10
SPI_MISO7: U8.22, X45.10
SPI_MOSI: U1.23, X2.9
SPI_MOSI1: U2.23, X9.9
SPI_MOSI2: U3.23, X15.9
SPI_MOSI3: U4.23, X21.9
SPI_MOSI4: U5.23, X27.9
SPI_MOSI5: U6.23, X33.9
SPI_MOSI6: U7.23, X39.9
SPI_MOSI7: U8.23, X45.9
SPI_SCK: U1.1, X2.11
SPI_SCK1: U2.1, X9.11
SPI_SCK2: U3.1, X15.11
SPI_SCK3: U4.1, X21.11
SPI_SCK4: U5.1, X27.11
SPI_SCK5: U6.1, X33.11
SPI_SCK6: U7.1, X39.11
SPI_SCK7: U8.1, X45.11
SWCLK: U1.6, X5.1
SWCLK1: U2.6, X11.1
SWCLK2: U3.6, X17.1
SWCLK3: U4.6, X23.1
SWCLK4: U5.6, X29.1
SWCLK5: U6.6, X35.1
SWCLK6: U7.6, X41.1
SWCLK7: U8.6, X47.1
SWDIO: U1.7, X5.2
SWDIO1: U2.7, X11.2
SWDIO2: U3.7, X17.2
SWDIO3: U4.7, X23.2
SWDIO4: U5.7, X29.2
SWDIO5: U6.7, X35.2
SWDIO6: U7.7, X41.2
SWDIO7: U8.7, X47.2
TGT_RX: IC2.4, U1.24
TGT_RX1: IC5.4, U2.24
TGT_RX2: IC8.4, U3.24
TGT_RX3: IC11.4, U4.24
TGT_RX4: IC14.4, U5.24
TGT_RX5: IC17.4, U6.24
TGT_RX6: IC20.4, U7.24
TGT_RX7: IC23.4, U8.24
TGT_TX: IC1.2, U1.4
TGT_TX1: IC4.2, U2.4
TGT_TX2: IC7.2, U3.4
TGT_TX3: IC10.2, U4.4
TGT_TX4: IC13.2, U5.4
TGT_TX5: IC16.2, U6.4
TGT_TX6: IC19.2, U7.4
TGT_TX7: IC22.2, U8.4
TX->: IC2.2, X3.4
TX->1: IC5.2, X7.4
TX->2: IC8.2, X13.4
TX->3: IC11.2, X19.4
TX->4: IC14.2, X25.4
TX->5: IC17.2, X31.4
TX->6: IC20.2, X37.4
TX->7: IC23.2, X43.4

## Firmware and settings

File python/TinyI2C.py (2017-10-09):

#!/usr/bin/env python3
# -*- coding: utf-8 -*-
# MIT License (c) K4ZUKI <https://github.com/K4zuki>

import serial
import os.path
import time

# Table 3. ASCII commands supported by SC18IM700
# ASCII command Hex value Command function
# [X] S 0x53 I2C-bus START
# [X] P 0x50 I2C-bus STOP
# [X] R 0x52 read SC18IM700 internal register
# [X] W 0x57 write to SC18IM700 internal register
# [X] I 0x49 read GPIO port
# [X] O 0x4F write to GPIO port
# [X] C 0x43 change channel
# [X] E 0x45 SPI transfer start

# "C| '0'| P"
# "C| '1'| P"
# "C| '2'| P"
# "C| '3'| P"
# "S| 0x_8 _0| 0x_0 _4| 0x_D _E _A _D _B _E _A _F| P"
# "S| 0x_8 _0| 0x_0 _4| 0x_D _E _A _D _B _E _A _F| S| 0x_8 _1| 0x_0 _4| P"
# "S| 0x_8 _1| 0x_0 _4| P"
# "R| '0'| P"
# "R| '0'| '1'| ...| P"
# "W| '0' 0x_a _a| P"
# "W| '0' 0x_a _a| '1' 0x_b _b| ...| P"
# "I| '0'| P"
# "O| '0'| 0x_a _a| P"


class TinyI2C(object):
    """ RS232C to I2C converter using mbed
    Example:
       dev = serial2i2c(port = 'com8', baud = '115200')

       for reg in range(0x050, 0x300, 0x10):
           print "%03X," %(reg),
           print dev.write_and_read((0xD0|((reg&0x300)>>7)), reg&0xFF, 16)

    Keyword Args:
        port (str): COM port where device is conected
        baud (str): baudrate

    """
    bus = None
    channel = 0
    wait = 1e-3

    CHIP_ID = '0'
    """ Register 0

    Read only

    Returns:
        chip ID to identify device
    """

    GPIO0_STAT = '1'
    """ Register 1

    Readable / Writable

    Args:
        status 1 to set 'H' or 0 to set 'L' on each corresponding GPIO0 pin
    Returns:
        status of GPIO0
    """

    GPIO1_STAT = '2'
    """ Register 2

    Readable / Writable

    Returns:
        Status of GPIO1 if enabled, 0xAA if disabled
    """
    GPIO0_CONF = '3'
    """register 3

    Readable / Writable
    """

    GPIO1_CONF = '4'
    # register 4; rw;

    I2C_CONF = '5'
    # register 5; rw;

    SPI_CONF = '6'
    # register 6; rw;

    def __init__(self, port='com1', baud='115200'):
        try:
            self.bus = serial.Serial(port, baudrate=baud, timeout=0.1)
        except SerialException:
            raise

    def setChannel(self, channel=0):
        """ sets channel by sending "C" command packet

        Args:
            channel (int): I2C bus channel

        Returns:
            str: response from module
        """
        assert(isinstance(channel, int))
        self.channel = channel
        packet = ["C",
                  str(self.channel),
                  "P"]
        self.raw_write("".join(packet))
        time.sleep(self.wait)
        return self.raw_read()

    def read(self, address, length=1):
        """ reads multi byte data

        Args:
            address (int): 8bit I2C slave address in HEX
            length (int): bytes to read

        Returns:
            str: ACK/NAK + response string from device
        """

        packet = ['S', 'P']

        address = self.hex2ascii(address, 0x30)
        alength = len(address) / 2
        packet.insert(1, chr(ord(address[0]) | 1))
        packet.insert(1, address[1])

        for l in self.hex2ascii(length, 0x30):
            packet.insert(3, l)

        self.raw_write("".join(packet).encode(ascii))

        time.sleep(self.wait * length * 2)
        return self.raw_read().decode('utf-8')

    def write(self, address, data=0):
        """ writes multi byte data

        Args:
            address(int) 8bit I2C slave address in HEX
            data(int): data to send

        Returns:
            str: ACK/NAK + response string from device
        """
        packet = ['S', 'P']

        address = self.hex2ascii(address, 0x30)
        alength = len(address) / 2
        [packet.insert(1, addr) for addr in address]

        data = self.hex2ascii(data, 0x30)
        length = len(data) / 2

        [packet.insert(3, l) for l in self.hex2ascii(length, 0x30)]

        [packet.insert(5, d) for d in data]

        self.raw_write("".join(packet))

        time.sleep(self.wait * length * 2)
        return self.raw_read()

    def write_and_read(self, address, wdata=0, rlength=1):
        """ writes data and then reads from same slave device

        Args:
            address(int): I2C slave address in HEX
            wdata(int): data to send in HEX
            rlength(int): bytes to read

        Returns:
            str: ACK/NAK + response string from device
        """
        packet = ['S', 'S', 'P']

        address = self.hex2ascii(address, 0x30)
        alength = len(address) / 2
        [packet.insert(1, addr) for addr in address]

        wdata = self.hex2ascii(wdata, 0x30)
        wlength = len(wdata) / 2

        [packet.insert(3, wlen) for wlen in self.hex2ascii(wlength, 0x30)]

        [packet.insert(5, wd) for wd in wdata]

        packet.insert(6 + wlength * 2, chr(ord(address[0]) | 1))
        packet.insert(6 + wlength * 2, address[1])

        for rlen in self.hex2ascii(rlength, 0x30):
            packet.insert(8 + wlength * 2, rlen)

        self.raw_write("".join(packet))

        time.sleep(self.wait * rlength * 2)
        return self.raw_read().decode('utf-8')

    def write_and_read_SPI(self, wlength=1, rlength=0, data=0xC4FEE0CA):
        """ writes data and then reads from same SPI device

        Args:
            wlength(int): length to write
            rlength(int): length to read
            data(int): data to send

        Returns:
            str: ACK/NAK + response string from device
        """

        _wlength = self.hex2ascii(wlength, 0x30)
        _rlength = self.hex2ascii(rlength, 0x30)
        _data = self.hex2ascii(data, 0x30)

        _wlength.reverse()
        _rlength.reverse()
        _data.reverse()

        packet = []
        packet.append('E')
        packet.extend(_wlength)
        packet.extend(_rlength)
        packet.extend(_data)
        packet.append('P')
        self.raw_write("".join(packet))

        time.sleep(self.wait * rlength * 2)
        return self.raw_read()

    def raw_write(self, data="C4FEE0CA"):
        # sends raw data on serial port
        self.bus.write(data.encode('ascii'))

    def raw_read(self):
        # reads raw data from serial port
        return (self.bus.readline().strip().decode('utf-8'))

    def start(self):
        # sends 'S' command packet to make start condition
        self.bus.write("S")

    def stop(self):
        # sends 'P' command packet to make stop condition
        self.bus.write("P")
        time.sleep(self.wait)

    def reg_read(self, registers="012"):
        """ reads data from device's own register

        Args:
            registers(str): register addresses

        Returns:
            str: response string from device
        """
        packet = "".join(["R",
                          registers,
                          "P"])

        self.raw_write(packet)
        return self.raw_read()

    def reg_write(self, pair=[('1', 0xFF), ]):
        """ writes data into device's own register

        Args:
            pair(list): register list of number and data list

        Returns:
            str: response string from device
        """
        packet = ['W', 'P']

        for _p in pair:
            reg, data = _p
            data = self.hex2ascii(data, 0x30)
            data.reverse()

            packet.insert(1, reg)
            packet.insert(2, "".join(data))

        length = len(packet)
        # print "".join(packet)
        self.raw_write("".join(packet))

        time.sleep(self.wait * length)

        return self.raw_read()

    def hex2ascii(self, h, mask=0x30):
        """ converts hex data to string
        Args:
            h(int): data in HEX
            mask(int): mask data in HEX, LSB must be 0, MSB must not be 0 (0x?0, ?>8)

        Returns:
            list: converted format in list
        """
        h = int(h)
        assert isinstance(h, int)
        chars_in_reverse = []
        chars_in_reverse.append(chr(mask | (h & 0x0F)))
        chars_in_reverse.append(chr(mask | ((h >> 4) & 0x0F)))
        h = h >> 8
        while h != 0x0:
            chars_in_reverse.append(chr(mask | (h & 0x0F)))
            chars_in_reverse.append(chr(mask | ((h >> 4) & 0x0F)))
            h = h >> 8

        return (chars_in_reverse)


if __name__ == "__main__":
    print ("please try test.py")

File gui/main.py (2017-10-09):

#!/usr/bin/python3
# -*- coding: utf-8 -*-

import sys
import os
from PyQt5 import QtCore, QtGui, QtWidgets

# from tinyI2Cgen import Ui_Form, _fromUtf8
from tinyI2Cgui import Ui_Form, _fromUtf8

from serial.tools.list_ports import comports as serial_comports

sys.path.append('../python')
import TinyI2C
import time
import serial


# how to make GUI from ui
#
class MyWidget(QtWidgets.QWidget):

    # SIGNAL definition
    readI2C_signal = QtCore.pyqtSignal(object)
    writeI2C_signal = QtCore.pyqtSignal(object)
    readGPIO_signal = QtCore.pyqtSignal(object)
    writeGPIO_signal = QtCore.pyqtSignal(object)
    updateI2Cspeed_signal = QtCore.pyqtSignal(object)
#    updateCheckbox_signal = QtCore.pyqtSignal(object)

    isUI = False
    ports = []
    i2c = None

    def __init__(self, parent=None):
        super(MyWidget, self).__init__(parent)
        self.setWindowFlags(self.windowFlags() | QtCore.Qt.CustomizeWindowHint)
        self.setWindowFlags(self.windowFlags() & ~QtCore.Qt.WindowMaximizeButtonHint)

    def getUI(self, gui):
        self.gui = gui
        self.isUI = True
        try:
            if os.name == 'posix':
                self.i2c = TinyI2C.TinyI2C(port="/dev/ttyS0")
            else:
                self.i2c = TinyI2C.TinyI2C()
        except:
            pass

    def _search(self):
        self._list()

    def _list(self):
        bus = 0
        _dummy = [0, 0, 0]
        _ports = []
        _idx = len(self.ports)

        if(self.isUI):
            self.gui.portList.clear()
            if(self.i2c):
                self.i2c.bus.close()
            for port in serial_comports():
                _dummy[0], _dummy[1], _dummy[2], = port
#                print "_list()", _dummy[0]
                try:
                    bus = serial.Serial(port=_dummy[0])
                except:
                    pass
                else:
                    bus.close()
                    _ports.append(": ".join(_dummy[:-1]))
                    self.ports.append(port[0])
#                    print "_list()", self.ports

            self.ports = self.ports[_idx:]

            self.gui.portList.addItems(_ports)
            self._setup(0)

    def _setup(self, _port=0):
        if(self.isUI):
            if(self.i2c and self.i2c.bus.isOpen()):
                self.i2c.bus.close()
#            print ("_setup()", self.ports)
            try:
                self.i2c = TinyI2C.TinyI2C(port=self.ports[_port])
            except:
                pass

    def _null(self):
        pass

    def readI2CSlot(self, arg):
        _slave, _channel, _register, _dest = arg
        if(self.i2c):
            read = self.i2c.setChannel(_channel)
            read = self.I2CregRead(_slave, _register)
            if read:
                _dest.setValue(int(read, 16))

    def writeI2CSlot(self, arg):
        _slave, _channel, _register, _data = arg
        if(self.i2c):
            self.i2c.setChannel(_channel)
            self.I2CregWrite(_slave, _register, _data)

#        CHIP_ID = '0',
#        GPIO0_STAT = '1',
#        GPIO1_STAT = '2',
#        GPIO0_CONF = '3',
#        GPIO1_CONF = '4',
#        REG5,
#        REG6,
#        REG7,
#        REG8,
#        REG9,
# "R| '0'| P"
# "R| '0'| '1'| ...| P"
#    def reg_read(self, registers = "012"):

    def readGPIOSlot(self, arg):
        print("readGPIOslot()")
        _sender = self.sender()
        _register, _dest = arg
        if(self.i2c):
            self.i2c.raw_read()
            read = self.i2c.reg_read(_register).split(",")[0]
            if read:
                read = int(read, 16)
                _dest.setValue(0)
                _dest.setValue(1)
                _dest.setValue(read)

    def writeGPIOSlot(self, arg):
        print("writeGPIOslot()")
        _register, _data, _dest = arg
        if(self.i2c):
            read = self.i2c.reg_write([[str(_register), _data]])
            read = self.i2c.reg_read(_register).split(",")[0]
            if read:
                read = int(read, 16)
                _dest.setValue(0)
                _dest.setValue(1)
                _dest.setValue(read)

    def I2CregRead(self, slave=0x90, reg=0x00):
        packet = []
        if not isinstance(slave, int):
            slave = int(slave)
        if not isinstance(reg, int):
            reg = int(reg)
        slave = self.i2c.hex2ascii(slave, mask=0x30)
        reg = self.i2c.hex2ascii(reg, mask=0x30)
        length = self.i2c.hex2ascii(len(reg) / 2, mask=0x30)

        slave.reverse()
        length.reverse()
        reg.reverse()

        packet.extend(slave)
        packet.extend(length)
        packet.extend(reg)
        packet.insert(0, 'S')
        packet.append('S')

        slave[1] = chr(ord(slave[1]) | 1)
        length = self.i2c.hex2ascii(1, mask=0x30)

        length.reverse()

        packet.extend(slave)
        packet.extend(length)
        packet.append('P')

        self.i2c.raw_write("".join(packet))
        time.sleep(self.i2c.wait * 2)
        read = self.i2c.raw_read()
        read = read.split(",")
        # print read
        if len(read) >= 2:
            return read[1]
        else:
            # print "Error"
            return ""

    # writes data to register address in selected slave address
    # copy and modify from tempcommand/instr_local.serial_i2c
    # @param slave slave address in HEX
    # @param reg register address in HEX
    # @param data data in HEX
    # @return created packet
    def I2CregWrite(self, slave=0x90, reg=0x00, data=0x00):
        #        print "I2CregWrite()",

        packet = []
        if not isinstance(slave, int):
            slave = int(slave)
        if not isinstance(reg, int):
            reg = int(reg)
        if not isinstance(data, int):
            data = int(data)
        slave = self.i2c.hex2ascii(slave, mask=0x30)
        reg = self.i2c.hex2ascii(reg, mask=0x30)
        data = self.i2c.hex2ascii(data, mask=0x30)
        length = self.i2c.hex2ascii(len(reg) / 2 + len(data) / 2, mask=0x30)

        slave.reverse()
        length.reverse()
        reg.reverse()
        data.reverse()

        packet.extend(slave)
        packet.extend(length)
        packet.extend(reg)
        packet.extend(data)

        packet.insert(0, 'S')
        packet.append('P')

        self.i2c.raw_write("".join(packet))
        _read = self.i2c.raw_read()
        return packet
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

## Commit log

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2015-01-03 [NEW] added gerber files
    [tinyI2C_P.GBL, tinyI2C_P.GBS, tinyI2C_P.GTL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]
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2015-01-05 sch and brd update
    [tinyI2C.brd, tinyI2C.sch]
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2015-01-05 [ NEW ] eagle setting files
    [DRILEGEND.CFG]
2015-01-05 [ NEW ] panelized brd file
    [tinyI2C_P.brd]
2015-01-05 panelize update
    each edge has 0.4mm margin
    [tinyI2C.brd, tinyI2C.sch]
2015-01-05 [ GERBER ] update
    panelized
    [tinyI2C_P.brd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]
2015-01-05 1.8V trace get wider
    [tinyI2C.brd]
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2015-01-05 library update; change pin-1 mark
    [tinyI2C.brd]
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2015-01-05 [ BRD ] silk change
    [tinyI2C.brd]
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2015-01-06 [ BRD ] L1 color change
    [tinyI2C.brd]
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2015-01-06 [ SCH ] pullups moved
    [tinyI2C.sch]
2015-01-06 Revert "via moved"
    This reverts commit aaa9bf2bf6dd5e57d443efd5f18dd7b2762135bb.
    [tinyI2C.brd]
2015-01-06 Revert "Revert "via moved""
    This reverts commit 887c96878196973ea542345829e1096b9f4be77a.
    [tinyI2C.brd]
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2015-01-07 fixed a stupid bug
    it was not sending any packet
    [main.py]
2015-01-07 [ NEW ] pcb directory all PCB design files moved into pcb directory
    [DRILEGEND.CFG, tinyI2C.brd, tinyI2C.sch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]
2015-01-07 changed import and related to match pyinstaller issue pyinstaller2.2 fixes this issue(pip is still 2.1)
    [hexSpinbox.py, main.py, serial2i2c.py]
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2015-01-08 [ GUI ] import path replaced
    [main.py]
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2015-01-10 [ PCB ][ SCH ] BOM changed IC2: TPS76318(0.2A) -> TPS73618(0.4A) 296-15816-1-ND
    [tinyI2C.sch]
2015-01-10 Revert "[ PCB ][ SCH ] BOM changed IC2: TPS76318(0.2A) -> TPS73618(0.4A) 296-15816-1-ND"
    This reverts commit bf9a7c92ce0625db0ef1a7f94382dcf04396bf4d.
    [tinyI2C.sch]
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2015-01-10 [ PCB ][ SCH ] BOM changed IC2: TPS76318 -> TPS73618
    [tinyI2C.sch]
2015-01-11 [ PCB ][ SCH ] all pins on pin headers
    [tinyI2C.sch]
2015-01-11 [ PCB ][ BRD ] all pins on pin headers - added X5 for SWD - R1,R3,R4 moved
    [tinyI2C.brd]
2015-01-11 [ PCB ][ SCH ][ BRD ] U1 replaced U1 is using mylib related trace change
    [tinyI2C.brd, tinyI2C.sch]
2015-01-11 [ PCB ][ SCH ][ BRD ] IC1, C5 update IC1: better footprint C5: smaller footprint
    [tinyI2C.brd, tinyI2C.sch]
2015-01-11 [ PCB ] U1 update as per library update
    [tinyI2C.brd, tinyI2C.sch]
2015-01-11 [ PCB ][ BRD ] cable color marked on bottom layer U1 silk moved
    [tinyI2C.brd]
2015-01-11 [ PCB ] panelized as per update
    [tinyI2C_P.brd]
2015-01-11 [ PCB ] trace change and panelize
    [tinyI2C.brd, tinyI2C.sch, tinyI2C_P.brd]
2015-01-11 [ PCB ][ GERBER ] update
    [tinyI2C_P.GBL, tinyI2C_P.GBS, tinyI2C_P.GTL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]
2015-01-13 [ PCB ][ SCH ] new header for ISP
    added ISP header
    removed connection to X1[3]
    renamed other headers
    [tinyI2C.sch]
2015-01-13 [ PCB ][ BRD ] new header for ISP
    added ISP header next to RESET header
    removed trace to X1[3]
    moved R3 to near th header
    silkn name and bottom VDD trace change
    [tinyI2C.brd]
2015-01-13 [ PCB ][ SCH ] LDO and buffer replace
    LDO replaced to MIC5355(Micron, 2 outputs) IC2-> IC3
    (Vout1 = 3.3V, Vout2 = 1.8V)
    125 buffer replaced to 2x single chip buffers(IC1,IC2) package: SC-70
    3.3V line added
    C7 added for 3.3V buffer
    C3 changed for 3.3V line
    [tinyI2C.sch]
2015-01-13 [ PCB ][ BRD ] LDO and buffer replace
    LDO replaced to MIC5355(Micron, 2 outputs, Vout1=3.3V, Vout2=1.8V) IC2
    -> IC3
    3.3V line added as LDO changed
    3-state buffer replaced from 1x quad to 2x single
    disconnect CTS, RTS
    [tinyI2C.brd]
2015-01-13 [ PCB ][ SCH ] new header X7 X7[1] = P0_13 X7[2] = P0_1
    [tinyI2C.brd]
2015-01-13 [ PCB ][ BED ] new header X7 addition related move added silk for ISP/RST font size change: 1.0,1.2,1.3mm/15%
    [tinyI2C.sch]
2015-01-14 [ PCB ][ SCH ] R and C library replace
    standard rcl lib to mylib
    [tinyI2C.sch]
2015-01-14 [ PCB ][ BRD ] R and C library replace
    standard rcl to mylib
    [tinyI2C.brd]
2015-01-14 [ PCB ][ SCH ] pull-up direction changed
    [tinyI2C.sch]
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2015-01-14 [ PCB ][ SCH ] X1[3] is now Vin(5V) [ BRD ] related tracechange
    [tinyI2C.brd, tinyI2C.sch]
2015-01-15 [ PCB ][ SCH ] library update related fix and move
    IC3 symbol updated; fixed schematic
    [tinyI2C.sch]
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2015-01-15 [ GUI ] Serial port search function fix
    it will try to open eache port each time [Search] button pressed
    [main.py]
2015-01-15 [ PCB ][ SCH ] BOM update
    [tinyI2C.sch]
2015-01-16 [ PCB ][ SCH ] replace as library did [ BRD ] I2C / SPI silk indicator
    [tinyI2C.brd, tinyI2C.sch]
2015-01-16 [ PCB ][ BRD ] C4 moved / C3 and C7 silk moved
    [tinyI2C.brd]
2015-01-16 [ GUI ] serial port intialisation fix
    [main.py]
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2015-01-18 [ GUI ] serial port selection bug fix
    [main.py]
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2015-01-19 [ GUI ] hexSpinbox regular expression fix
    0x?? -> ??
    [hexSpinbox.py, main.py, tinyI2Cgui.py]
2015-01-19 Revert "[ GUI ] hexSpinbox regular expression fix"
    This reverts commit f47c741ed80f932c771c0f988c5de0ce96ba1a1d.
    [hexSpinbox.py, main.py, tinyI2Cgui.py]
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2015-01-20 [ GUI ][ Qt ] GPIO UI fix
    all registers are named
    UI changed to toggle button
2015-01-20 [ GUI ] checkClick() fix
    the function watches button toggle event and update writing data
    [main.py]
2015-01-20 [ GUI ][ Qt ] UI fix unused registers; button is checkable + flat
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2015-01-21 [ MBED ][ LPC824 ] ifdef TINYI2C fix
    TINYI2C switch was oppsite
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2015-01-21 [ GUI ] I2CregRead() fix
    based on I2C response change
    [main.py]
2015-01-21 [ PCB ][ SCH ] add OSC, capacitors/ replace SPI pins P0_8/P0_9 to be OSC pins added Q1/C8/C9 P0_1 -> SPI CS P0_13 -> SPI SCK
    [tinyI2C.sch]
2015-01-21 [ PCB ][ BRD ] placement as per schematic change
    [tinyI2C.brd]
2015-01-21 [ PCB ] panelized based on sch/brd updates
    [tinyI2C_P.brd]
2015-01-21 [ PCB ][ GERBER ] update based on brd fix 9037338ab0909b0d8c75574fc36787287275a06b
    [tinyI2C_P.GBL, tinyI2C_P.GBS, tinyI2C_P.GTL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]
2015-01-21 [ PCB ][ SCH ][ BRD ] fix as library did; trace fix
    [tinyI2C.brd, tinyI2C.sch]
2015-01-22 [ PCB ][ SCH ] BOM update
    Q1 is 12MHz; CL for Q1(C8-9) = 18pF, 1005
    [tinyI2C.sch]
2015-01-22 [ PCB ][ BRD ] silk update as library did
    silk Cs and Rs are updated; additional fix for it
    board name is on top metal layer now(was: top silk layer)
    [tinyI2C.brd]
2015-01-22 [ GUI ] hexSpinbox.py fix as ui file did
    [tinyI2Cgui.py]
2015-01-22 [ GUI ] hexSpinbox.py and tinyI2Cgui.py fixes
    as ui file did
    [hexSpinbox.py]
2015-01-22 [ PCB ][ SCH ] BOM update
    C5 also uses 10uF instead of 1.0uF
    [tinyI2C.sch]
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2015-01-22 [ PCB ] panelize as updated
    [tinyI2C_P.brd]
2015-01-22 [ PCB ][ GERBER ] update based on brd fix
    [tinyI2C_P.GBL, tinyI2C_P.GBS, tinyI2C_P.GTL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]
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2015-01-27 [ MBED ][ LPC824 ] SPI register write fix
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2015-01-29 [ GUI ][ PyQt ] I2C/SPI registers
    as per .ui fix
    [tinyI2Cgui.py]
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2015-02-02 [ GUI ] SPI packet length to be fixed 8 bit
    available 8/16 bits but fixed on GUI
    [tinyI2Cgui.py]
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2015-02-02 [ PCB ][ BRD ] all silk fix, via on IC3-EP, U1-placement, traces, Q1 lib change silk = 0.2mm fonts = 1.0mm/20%(0.2mm)
    [tinyI2C.brd]
2015-02-02 [ PCB ][ SCH ] IC3-NCs connection, silk fix IC3 = NCs are connected to GND silk = 0.2mm
    [tinyI2C.sch]
2015-02-03 [ PCB ][ SCH ][ BRD ] add/replace GND testpad
    TP07R(0.7mm SMD pad) to 2x TPB1.27(1.27mm SMD pad)+0.8mm via
    [tinyI2C.brd, tinyI2C.sch]
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2015-02-03 [ PCB ][ BRD ] GND TP slight move
    [tinyI2C.brd]
2015-02-06 [ PCB ][ BRD ] U1 EP, 1.8V line
    U1 EP has changed to circle via
    [tinyI2C.brd]
2015-02-16 [ PCB ][ BRD ] silk alignment
    all silks are aligned on 0.1mm grid
    [tinyI2C.brd]
2015-02-17 [ PCB ][ SCH ] library update
    IC_LDO_MIC5355 updated
    [tinyI2C.sch]
2015-02-17 [ PCB ][ BRD ] silk/library update
    Silk: pin 1 indicator added (x3)
    Library: mylib; IC_LDO_MIC5355; related trace change
    [tinyI2C.brd]
2015-02-17 [ PCB ][ BRD ] IC2/C1 moved; 1.8V line narrowed
    IC2: turned 90deg CW
    C1: moved to fit
    1.8V: narrowed; getting wider GND
    [tinyI2C.brd]
2015-02-23 [ PCB ][ SCH ] R, C, BOM
    [tinyI2C.sch]
2015-02-23 [ PCB ][ NEW ] BOM file
    [tinyI2C.csv]
2015-02-24 [ PCB ] Q1 silk
    [tinyI2C.brd, tinyI2C.sch]
2015-02-25 [ PCB ] BOM fix
    semicolone to comma
    [tinyI2C.csv]
2015-05-24 [ PCB ] add minlab icon;panel fix
    [tinyI2C.brd, tinyI2C.sch]
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2015-08-25 [ PCB ] library update
    [tinyI2C.brd, tinyI2C.sch]
2015-08-25 [ PCB ] outline size shrinked
    [tinyI2C.brd]
2015-08-25 [ PCB ][ BRD ] V-CUT mark inserted
    [tinyI2C.brd]
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2015-08-29 [ PCB ] panel/drill size change, V-CUT mark, Panelize
    [tinyI2C.brd, tinyI2C_P.brd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]
2015-09-16 [ FIX ] horizontal milling width increased to 1.0mm
    [tinyI2C.brd]
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2015-10-06 [mbed] correct SPI setting
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2015-11-04 [ PCB ][ SCH ] FIDUCIAL from library
    [tinyI2C.brd, tinyI2C.sch]
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2016-09-03 [ GUI ] main.py: error process added
    - readI2CSlot()
    - readGPIOSlot()
    - writeGPIOSlot()
    - I2CRegRead()
    [main.py]
2016-09-03 [ GUI ] fix main.py - I2CregRead() error process
    - fix tinyI2C.spec
    - fix hexSpinbox.py
    [hexSpinbox.py, main.py]
2016-09-04 [ GUI ] add error process for Windows serial port
    - for error of COM1-not-found error on windows
    [main.py]
2016-09-04 [ GUI ] error processing
    - main.py: will not try accesses if UART connection
    does not exist
    [main.py]
2016-09-09 [ NEW ] Sections 1 and 2 added
    - doc/TITLE.md: includes 1.0_tinyI2Cabstract.md
    - doc/data/commansSandP.csv: [NEW] S and P commands description table
    - doc/1.0_tinyI2Cabstract.md: [NEW] translating /README.md into two sections
    [commandSandP.csv]
2016-09-10 [ NEW ] add commands S & P repeated start, registers 3~5 tables
    [commandSandP_SSP.csv, register3.csv, register4.csv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]
2016-09-12 [ DOC ] fix sections 1 and 2
    Section1:
    - add demo program usage
    Section2:
    - Basic protocol description
    - I2C command packet descriptions
    -- S/P
    -- C
    - fix other tables
2016-09-13 [ DOC ] add command R and W packet table
    [commandRandW_multi.csv]
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2016-09-14 [ DOC ] no force-CRLF; update MMDs; update and add tables
    fix .gitattributes to disable auto CRLF
    add C command csv table
    add S and P commands' read only case csv table
    add S and P commands' read only return packet csv table
    [commandC.csv, commandRandW_multi.csv, commandSandP_ro.csv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]
2016-09-14 [ DOC ] add registers 0/1/2/6 table csv
    - add register description listing table
    [register0.csv, register1.csv, register2.csv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]
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2016-09-15 [ DOC ] tailnote automation enabled
    - Makefile gets current git HEAD short hash
    - TITLE.md sets some more pandoc variables
2016-09-16 [ DOC ] fix and make Python API documents
    2.0_PythonAPI.md:
    - doxygen-like tables
    commandRandW_multi.csv, register5.csv:
    - fix for better TeX/PDF output
    [commandRandW_multi.csv, register5.csv]
2016-09-17 [ DOC ] fix API descriptions
    section 1:
    - fix description for SPI function
    section 2:
    - making better look of tables
    python - reg_write():
    - fix default argument to use touple
2016-09-18 [ DOC ] import PNG images, instead of tables, to make more visual waveforms
    [commandSandP_ro.csv, commandSandP_wo_bus.csv]
2016-10-16 [ PYTHON ] apply autopep8; fix test script
    [test.py]
2016-10-19 fix register description typo in table; fix Command details
    [register_list.csv]
2016-10-19 [ DOC ] add command E waveforms; add ascii vs. hex table
    [asciitable.csv]
2016-10-25 fix non-printed character
    - character '>' did not appear to both html/pdf outputs unless back-quoted
    [asciitable.csv]
2017-01-31 [ DOC ] start using bitfield for register description tables
    - register 0
    - register 1
    [register0.csv, register1.csv]
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2017-10-01 porting to python3 x Qt5
    - apply autopep8
    - print to print()
    - still having encoding issues
    [hexSpinbox.py, main.py, tinyI2Cgui.py]
2017-10-01 GUI: use mask=0x30 to bypass encoding error
    [main.py]
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
